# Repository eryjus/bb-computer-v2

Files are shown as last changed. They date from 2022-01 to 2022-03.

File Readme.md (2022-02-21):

# Breadboard Computer v2

This project is related to building hardware more than a software project.  There will be some code added to this project later on for programming the firmware and downloading a program, but that will be in the final stages.

This project is inspired by [Ben Eater's Breadboard Computer](https://eater.net/8bit).  Currently as this get started, I have his computer nearly complete and I am working on the final connections and debugging before I get into the control logic.

## Why?

I have always liked playing with hardware but never had any place to learn about it.  I stumbled on Ben Eater's 8-bit breadboard computer and it really sparked my interest.

OK, so why not build that one and call it a day?  Well, I did.  Or more the the point, I am.  However, there are some things I think need to be improved on.  Many of these come from my software developer (dare I call myself a software engineer?  I probably shouldn't) experience.

While I am completing the original computer and debugging it, it really all came to a head when all the control lines started to get in the way.

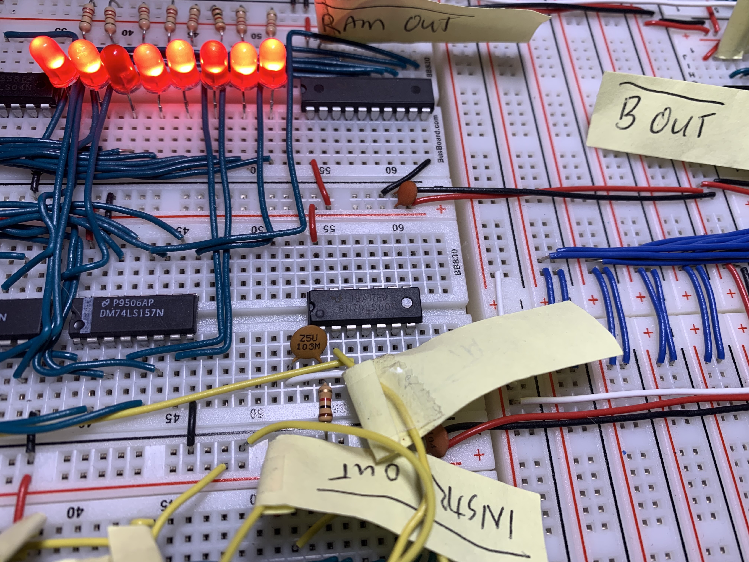
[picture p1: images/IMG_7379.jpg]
Control Lines


Not only are they all crushed down to the board to get them out of the way, but several leads were breaking from being worked so hard.

And then, there is the whole "active low" vs. "active high" issue.  There are a number of control lines which are active low meaning as long as you are asserting a "true" or 1 on the line it means, "Do not load any value from the bus."  This inversion in an interface point flicks my OCD buttons!  Big time!

## Videos

Hey, I tried it.  I made a few videos.  I did not like them.  I do not have the polish that Ben Eater does; I do not have the tools Ben Eater does.  Let's face it: he set a high standard and I cannot compete.

That said, I am also quite good at documenting my progress in projects.  I typically spend just as much time documenting as I do actually working on the project.  It helps me think things through (and believe it or not saves me time overall).

So, my goal is not to write a teaching video as Ben Eater did.  My goal is to document my progress as I go for others to review and enjoy -- and maybe get some ideas.  If you learn something from my mistakes, that's fantastic, too!

## Formal Experience?

Am I an electrical engineer?  No.

Do I have an extensive background in electronics?  No.

Am I learning as I go?  Yes.

Have I made mistakes?  Absolutely.

In fact: my first attempt at Ben Eater's Clock Module actually cooked one of the 555 Timer ICs.  I had to go find and order a replacement.  While I was at it I orders several other things I figured I would "break" along the way.  Now I have quite the collection going -- enough to prototype somethings on separate boards.

## Schematics

I was able to find KiCAD, an open source schematic drawing software.  It has natively all the elements that will be used to construct this computer.

I will be adding these files into the `kicad` folder in this project.

## Common Interface

I am going to be pulling the interface points to the edges of each board and making each row consistent for several interface points.  Additionally, all interface points will be converted to be active high.  As a result I will need to add an inverter to nearly all modules to properly handle that signal on-module.  But the point is to keep that kind of messiness away from the other modules.  Also, there are several modules which will have an inverter already on the module with unused gates.

Here is a picture of the updated Clock Module with the *clock* (white) and *output to bus* (yellow) interface rows tied together on the right side of the board.

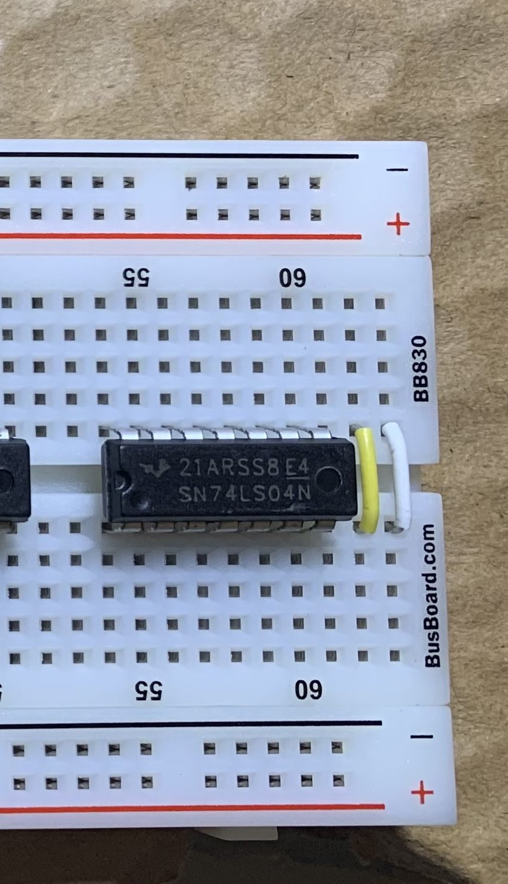
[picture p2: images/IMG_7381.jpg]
Interface Points


## Test Board

One of my goals is to be able to simplify testing of each module.  This is one of the driving reasons I am migrating to a common interface configuration.

To assist in this, I have created a test breadboard.  This board is intended to have all the inputs necessary to test the control lines and the outputs required to view the bus contents.  Here is a picture of this board:

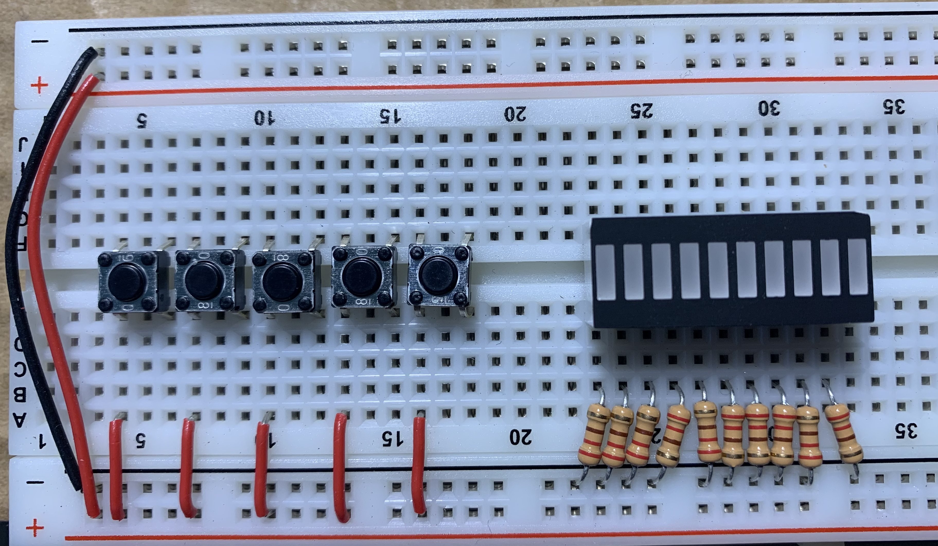
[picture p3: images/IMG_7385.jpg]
Test Board


The goal here is to quickly hook up wires and to be able to test the module functions more thoroughly before adding it into the final computer -- something I struggled to do with the original computer.

You have a high likelihood of finding my test rig in many of my pictures.

## 10-Segment LED Graph

I will replace the individual LEDs with a 10-segment LED graph for most modules (the most notable exception being the Clock Module).  These LED graphs have 8 green LED which will be used to represent data bits.  They also have an orange LED and a red LED which will be used to indicate reading data from the bus and writing data to the bus respectively.

With this change, the boards are able to get a higher density of LEDs and therefore a little more room on each board.  The drawback is that it will saturate the power rails for a section of the board and I may have to get creative when pulling power and ground to something else.

## Wire Colors

There are several color wires I plan to use -- a few more than Ben Eater used with the original computer.  These are:

| Color | Used for |
|:-----:|:---|
| Red | +5V or tied high |
| Black | Ground or tied low |
| White | Clock signal (regular or inverted) |
| Yellow | Control Lines |
| Blue | Data bus lines |
| Purple | Address lines |
| Green | Connections on-module |
| Brown | Manually input data and/or Arduino interface |
| Grey | Data Output (such as LED) and other connections not listed above |

## Overall Layout

| Left Column | Center Column | Right Column |
|:---:|:---:|:---:|
| (10) Clock Module | (20) Upper Program Counter | (30) Upper Temp 1 Register |
| (11) Upper MAR | (21) Lower Program Counter | (31) Lower Temp 1 Register |
| (12) Lower MAR | (22) Upper Flags | (32) Upper ALU |
| (13) Upper RAM | (23) Center Flags | (33) Lower ALU |
| (14) Lower RAM | (24) Lower Flags | (34) Upper Temp 2 Register |
| (15) Basic ROM | (25) Upper Stack | (35) Lower Temp 2 Register |
| (16) Upper A Register| (26) Lower Stack | (36) ALU Control 1 |
| (17) Lower A Register | (27) Bus Bridge | (37) ALU Control 2 |
| (18) Upper B Register | (28) Bus Contents | (38) ALU Control 3 |
| (19) Lower B Register | (29) CPU Constants | (39) Control Logic 1|
| (1A) Upper X Register | (2A) Upper Output | (3A) Control Logic 2|
| (1B) Lower X Register | (2B) Center Output | (3B) Control Logic 3|
| (1C) Reset Logic | (2C) Lower Output | (3C) Control Logic 4 |

## Modules

### Clock Module

The Clock Module is slightly modified version of [Ben Eater's Clock Module](https://eater.net/8bit/clock).  The schematic of his module is referenced below.

Ben Eater's Clock Module Schematic

The changes I am making to this module are:
1. Place yellow LED indicators on the astable and monostable timer circuits for visibility.
1. Place a green LED indicator on the switched circuit to show when the clock is in run mode (vs. single-step mode).
1. Add a red LED to indicate when the clock is halted by the control lines (the `HLT` signal).
1. Remove the inverted `CLK'` signal, which will be relocated to the Control Module where it is consumed.
1. Remove the OR gate and replace it with inverters and an AND gate (`A | B == (A' & B')'`).  See [2022-Jan-22 in the Journal](journals/Journal-01-Clock.md#2022-Jan-22) for a discussion and proof.
1. I am adding current-limiting resistors to every LED.  To be fair, Ben Eater's kits and instructions say that this is optional even though he does not use them in the videos.

### Program Counter Module

The Program Counter is nearly the same as [Ben Eater's version](https://eater.net/8bit/pc).  The original Program Counter is referenced below:

Ben Eater's Program Counter

Simply put, the changes the improved Program Counter are:
1. Make it a full 16-bits wide.
1. Since this is an 8-bit bus, make an upper and lower register, tied together.
1. There are 4 74LS161 counters tied together.
1. The original Program Counter had a bad habit of counting when it wasn't supposed to (on my boards anyway).  The improved Program Counter has a 100Ω pull-down resistor across Pin 2 of the lowest nibble 74LS161.
1. I use a 10-bar LED graph to indicate the data and control logic.  There are 8 green data LEDs, 1 yellow LED to indicate input from the bus, and 1 red LED to indicate output to the bus.  There is 1 graph for the upper Program Counter and another for the Lower Program Counter.
1. A 74LS04 Inverter was added to that the Control signals are inverted "locally" when required.  4 of the 6 inverters are utilized.

### Power-Up Reset / Zero Register Module

Ben Eater did not have this feature in the original computer.  The original computer had a reset button to clear everything on after manually programming.  I also plan to have a reset button, but I do not want to have to manually "reset" the computer on power up.

The reset button is tied into the power-up logic, not the Control Logic in the original computer.  The original computer's reset button can be seen [here](https://eater.net/schematics/control.png) in the bottom left corner of this schematic.

I also had problems getting the pull-down resistors to work properly on the bus.  Instead of pulling the bus values to 0, it left them floating.  I was not smart enough to figure out what the problem was, much less how to fix it (using the pull-down resistors anyway).  From the videos, I was not able to determine how this was tested.

Instead I made sure that every line was output to the bus even when there were only 4 bits to output (I tied the unassigned 4 bits low).  This cleaned up my problems.

In the improved version, I am going to add a Zero Register.  This register will output a 16-bit zero value on the bus and will be the default output register to the bus when nothing else is being output.

The Zero-Register is not really a register (more like a hard-coded zero value) and as such cannot be updated.

Since I have plenty of room on the Power-Up Module and the Zero Register will be placed on this board as well.  I am going to have plenty of boards.

### Arithmetic Logic Unit

The Arithmetic Logic Unit (ALU) is used to perform a number of operations between the values in 0, 1, or 2 registers.  In this implementation, the ALU and the Temporary Registers take several boards to complete.

The ALU also has a control module to handle a number of special cases with the Carry Flag and other flags.

The ALU supports 16 operations:

| ## | Operation | T1 | T2 |
|:--:|:---|:--:|:--:|
|  0 | NOT | Y  | |
|  1 | AND | Y  | Y  |
|  2 | NAND | Y  | Y  |
|  3 | OR | Y  | Y  |
|  4 | NOR | Y  | Y  |
|  5 | XOR | Y  | Y  |
|  6 | XNOR | Y  | Y  |
|  7 | FALSE | | |
|  8 | TRUE | | |
|  9 | ADD | Y  | Y  |
| 10 | SUB | Y  | Y  |
| 11 | SHL | Y  | |
| 12 | INC | Y  | |
| 13 | DEC | Y  | |
| 14 | ADC | Y  | Y  |
| 15 | SBB | Y  | Y  |

### General Registers

There are 8 basic registers that are included in this updated computer, not counting the Program Counter.  These are:
* A Register (Software accessible)
* B Register (Software accessible)
* X Register (Software accessible)
* Stack Register (Software accessible)
* Output Register (Write only; Software accessible)
* Memory Address Register (MAR)
* Temporary Register 1 (TR1)
* Temporary Register 2 (TR2)

## Control Signals

It occurs to me early on that I need to keep track of the control signals I am requiring, and what module they are associated with.

| ## | Module | Control Signal |
|:--:|:---:|:---:|
| 1  | Clock | Halt |
| 2  | Program Counter | Clear |
| 3  | Program Counter | Enable |
| 4  | Program Counter | Upper Byte In (JMP) |
| 5  | Program Counter | Upper Byte Out |
| 6  | Program Counter | Lower Byte In (JMP) |
| 7  | Program Counter | Lower Byte Out |
| 8  | Power-Up Reset  | Zero Register Out |
| 9  | Temp Register 1 | Clear |
| 10 | Temp Register 1 | Upper Byte In |
| 11 | Temp Register 1 | Upper Byte Out |
| 12 | Temp Register 1 | Lower Byte In |
| 13 | Temp Register 1 | Lower Byte Out |
| 14 | Temp Register 2 | Clear |
| 15 | Temp Register 2 | Upper Byte In |
| 16 | Temp Register 2 | Upper Byte Out |
| 17 | Temp Register 2 | Lower Byte In |
| 18 | Temp Register 2 | Lower Byte Out |
| 19 | ALU | Upper Byte Out |
| 20 | ALU | Lower Byte Out |
| 21 | ALU | Function Select 0 |
| 22 | ALU | Function Select 1 |
| 23 | ALU | Function Select 2 |
| 24 | ALU | Function Select 3 |

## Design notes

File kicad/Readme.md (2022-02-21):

# Kicad Drawings and Computer Organization

Before you get into the Kicad schematics, I want to touch on the computer layout a bit.  Overall, the computer is laid out in 3 columns with a bus between each column.

There are several breadboards in each column, with columns 1 & 3 having 13 breadboard and the middle column (2) having 12.  The extra space is taken up with a "bus bridge" to link the 2 buses together.

This is important for these drawings since the naming convention will indicate the breadboard location for any given schematic.  However, the computer is also organized into modules and some components may exist on a separate breadboard.

As an example, each 16-bit register has a 74LS04 Quad-AND Gate and a 74LS08 Hex-Inverter.  Each register is built on 2 breadboards.  One will have the 74LS04 and the other will have the 74LS08.  However, all the logic symbols will be located on a single schematic.  These facts need to be taken into account if you want to duplicate the boards.

So, that said, each schematic drawing will have a 2-character location specification where:
* the first character indicates its column (1, 2, 3)
* the second character indicates which row (hex from 0 to C)

See the [computer layout](../Readme.md#overall-layout) for more information.

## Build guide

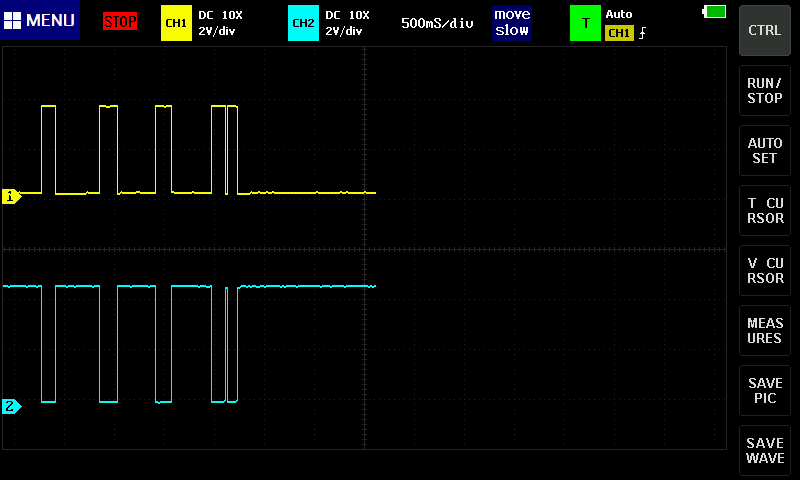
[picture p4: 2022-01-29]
images/manual bounce.bmp

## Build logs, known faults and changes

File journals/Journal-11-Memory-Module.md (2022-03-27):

# Breadboard Computer v2

This project is related to building hardware more than a software project.  There will be some code added to this project later on for programming the firmware and downloading a program, but that will be in the final stages.

This project is inspired by [Ben Eater's Breadboard Computer](https://eater.net/8bit).  Currently as this get started, I have his computer nearly complete and I am working on the final connections and debugging before I get into the control logic.

As usual with my personal projects, I am compelled to keep a journal of this progress.  As usual with my journals, I will not go back and edit anything historical as these are my continuing thoughts rather than documentation of the final product.

## Memory Address Module

This module is actually 2 registers and an adder:
* Memory Address Register (MAR) -- this will be an internal register which will be used to set a base memory address, typically from the Stack Pointer or Program Counter
* Memory Index Register (MIR) -- this will be an offset (forward or backward) from the Memory Address Register; every access to memory will use this Register and as such may be 0 much of the time
* Memory Address Adder (MAA) -- this will add the MAR and MIR together and the result of this operation will be used for every Memory access
* Memory Address Proper (MAP) -- this will be the actual address which will be used for every memory access

Each of these will only load values from the bus (none will output values to the bus).  Contrast that with the need to output the *contents* of the memory at the Memory Address Proper to the bus, which is a future module.

That said, this module will take a bit to build.  Each of the 4 sections above will be included in this module and Journal file.

---

## Memory Address Register (MAR) Sub-Module

---

### 2022-Feb-01

I'm not going to lie: for a little while I thought I could lay out the MAR on one board.  Actually, I can.  I thought I could keep the upper address byte on the top of the board and the lower on the bottom.  I can.  I was hopeful I could save a board.  I could.

*Except....*

The 8 lined that need to be brought down to the adder had absolutely no room on the breadboard and would need to be routed off-module or looped over the ICs.

I decided to keep the MAR separated to 2 breadboards.  This is consistent with the initial expected layout.  The dry layout (before wires) is very sparse:

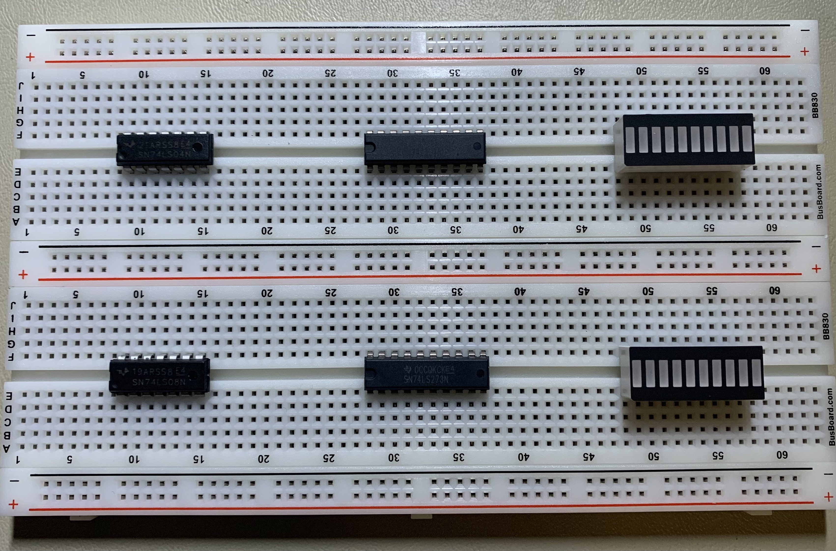
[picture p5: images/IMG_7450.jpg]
Memory Address Register Dry Layout


Notice that there is no 74LS245 IC -- since there is no need to output to the bus, there is no need for a tri-state buffer.  This saves me an IC on each breadboard.

Also (though it is not evident in the picture), the LED is facing the opposite direction so the cathodes are on top rather than on the bottom as with all the other modules built so far.  This will mean I do not want to attach this module to the Clock timer *after* it is built.  I will be assembling this attached to the Clock Module; please understand this fact when it makes an inevitable appearance in the pictures.

---

Now, I probably should consider how I am going to program the memory remotely.  I do plan on using an Arduino Nano to accomplish this.  For this to happen, I am going to need to set the MAR, MIR (to 0), and then populate the data on the bus and trigger a write from the bus to memory.

For this to work, I need to be able to load the MAR from 2 sources:
* From the bus when in run mode
* From the Arduino registers when in program mode

I will probably need to add a 74LS157 (2-to-1 decoder) to pull the address from the proper source.  Since the 74LS157 is a 4-bit decoder, I will need 4 of them.  Alternatively, I can program the upper and then lower MAR bytes separately and use twice the clock cycles to accomplish the programming cycle.

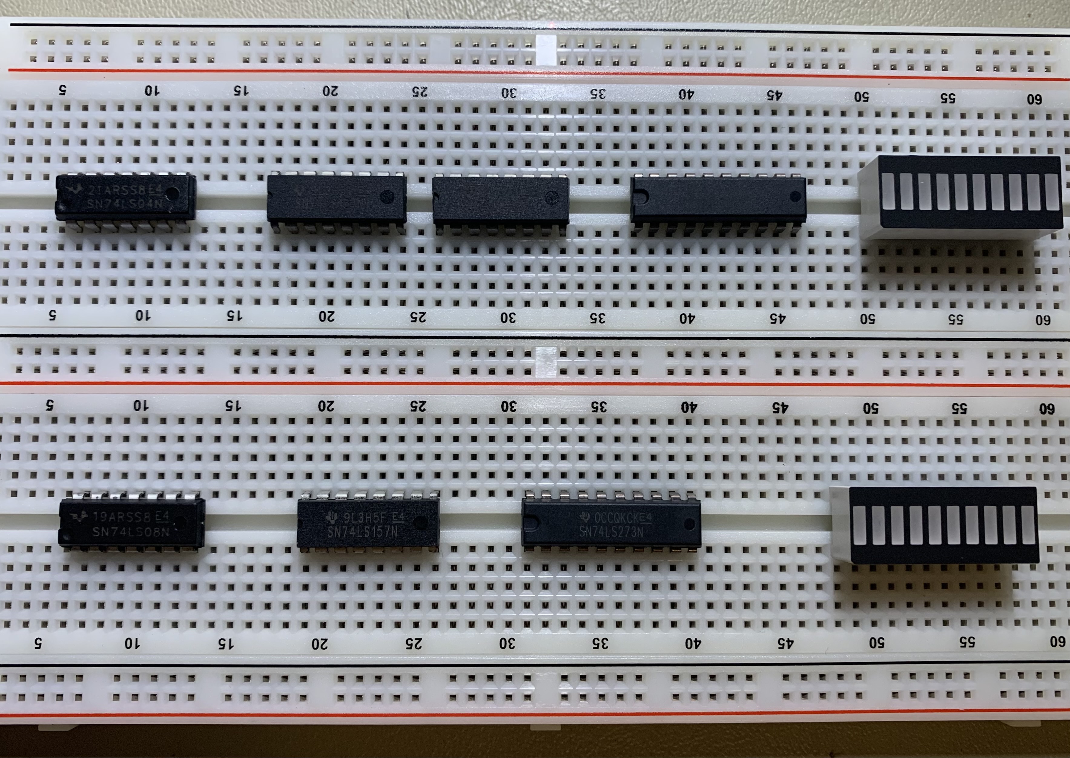
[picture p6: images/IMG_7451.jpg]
Sample Layout


The upper board would be if I was able to set all 16-bits of the address at the same time.  This would add ICs and reduce programming time.  I am concerned about power already.

The lower board would be if I was to set the upper and lower bytes separately.  This would effectively double the time it took to program the RAM.

A third alternative is to integrate directly into the bus and control logic so that there was effectively 2 sets of control logic.  I actually like the elegance of this design -- to take over the computer to program the RAM.  And this means I do not have to do anything special for the MAR.  But I may have to change the Clock Module to accommodate the separate clock source.

Hmmm.... I wonder if I could use a diode to keep the clock signal from back-bleeding into the clock and vice-versa from the Arduino....  I am going to order some and play with them on a board and oscilloscope.  In the meantime, I will do the foundational wire-up.

---

### 2022-Feb-02

I have the MAR completed.  It really was a simple wire-up.

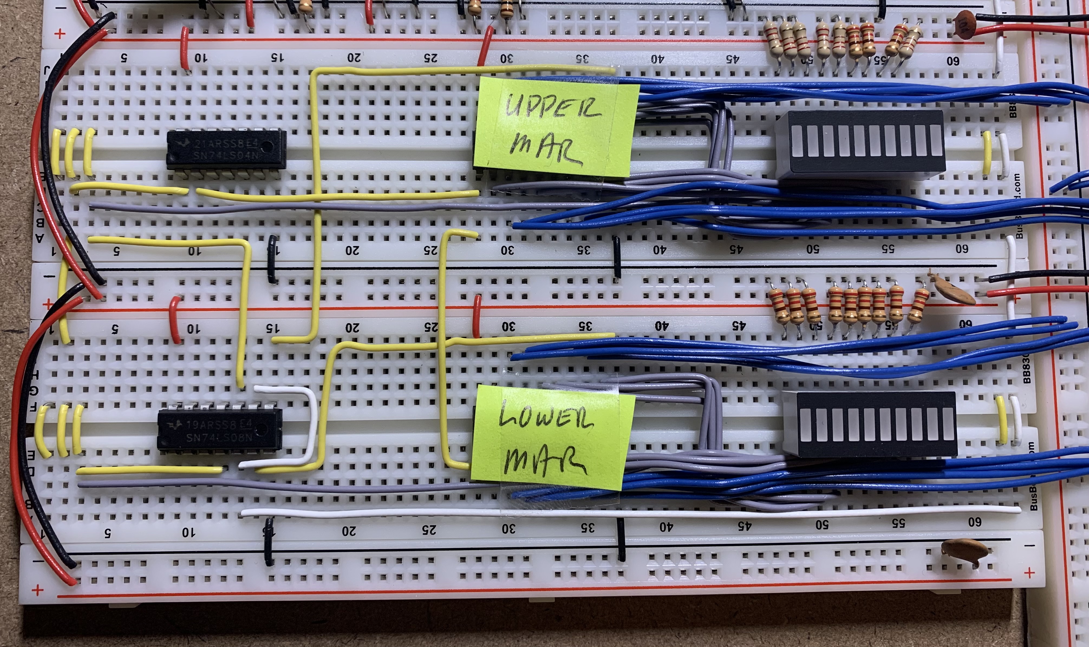
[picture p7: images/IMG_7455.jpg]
Completed MAR


It is also hooked up to the bus, along with all the other completed modules.

So, with this, I move on to the Memory Index Register (MIR).  It happens to be a complete duplicate of the MAR.  So...., second verse; same as the first!

---

## Memory Index Register (MIR) Sub-Module

This sub-module will be located immediately below the MAR.

---

### 2022-Feb-02 (continued)

The question is whether I leverage the MAR's existing 74LS04 and 74LS08 chips, which have enough capacity to host the MIR requirements.

The Inverter is only using 1 of 6 gates.  This is very wasteful.  The AND gate is 50% populated.  Again this is wasteful.  Especially since I am concerned about power.

The layout is still tight, but this is far more doable by splitting the 74LS04 & 74LS08 over 2 boards.

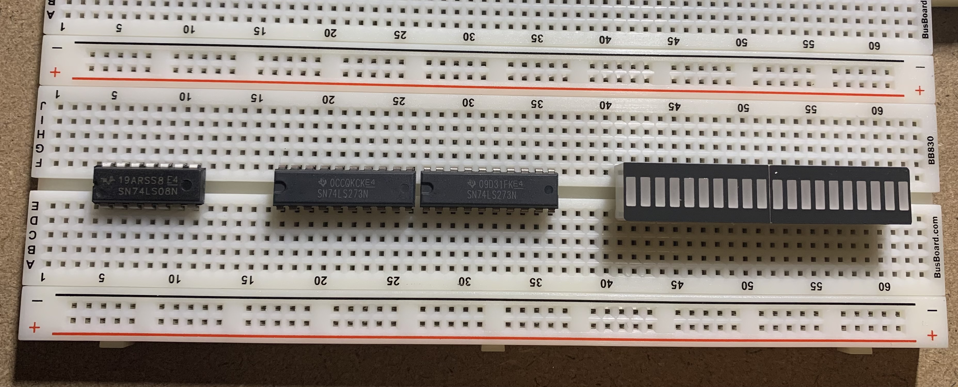
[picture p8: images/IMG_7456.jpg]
Layout for MAR & MIR on 2 boards revisited


I think the key to making this work is that the 74LS08 (AND gates) will be fully populated and if I need another AND gate, it will be in the adder or in the Memory Address Proper (MAP); however, the 74LS04 (Inverter) still has capacity and can be leveraged for the adder or the MAP.  So, the 74LS08 needs to be placed with the MAR whereas the 74LS04 can be placed with the MIR.

Of course, this means I need to tear up the MAR and redo it.

---

I knew things would get tight with the LED graphs..., and they did!

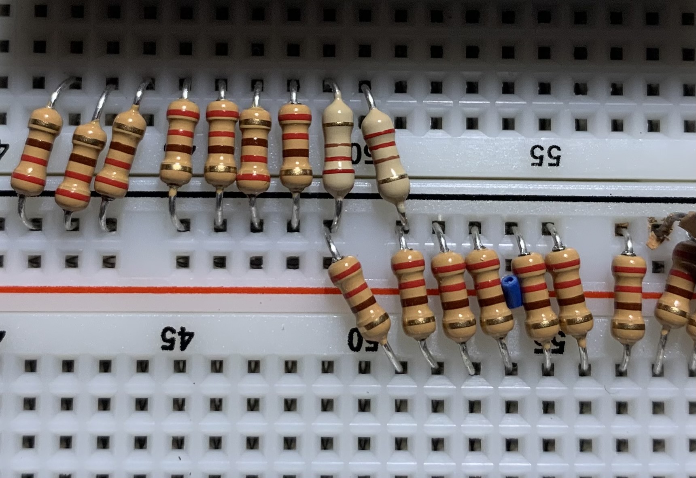
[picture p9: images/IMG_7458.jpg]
Tight Connections


Yes, there are 2 resistors doubled up in the ground connection.  I'm going to live with it for now.

I still have foundational connections to complete (again), but I am not up for all that (again) tonight.

---

### 2022-Feb-03

Today I completed the control lines.

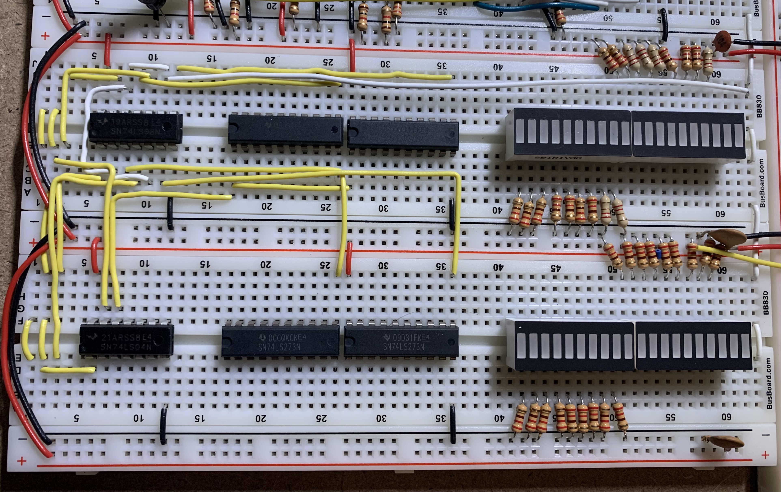
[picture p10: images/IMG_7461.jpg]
Control Lines Wired


---

Also, as a side note, I started working on a bench-top power supply from an old retired ATX power supply.  This old power supply is a 750W monster and will provide plenty of DC power for nearly all my needs.

I am not going to document this project, as there are plenty of videos and the like on how to do this.  I will post a picture of the results in a future journal.

---

### 2022-Feb-04

Well, last night I was able to get the MAR re-wired.  In the end it looked like this:

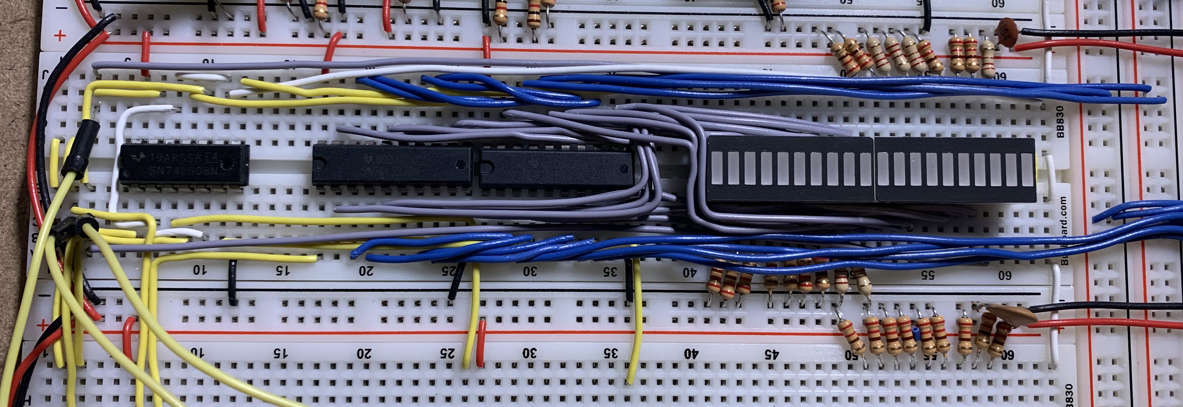
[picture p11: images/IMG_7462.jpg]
MAR Wired-Up Again


Today, I tackled the MIR and got that wired up as well.

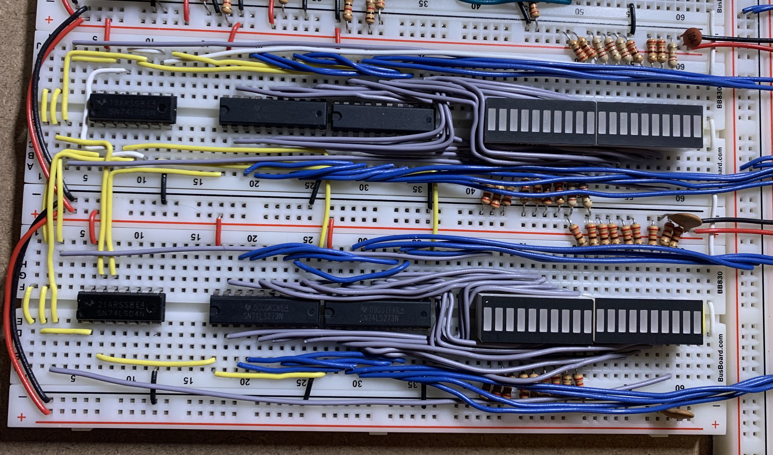
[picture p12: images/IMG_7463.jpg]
MIR Wired-Up


Both registers are properly tested (and in fact I had to wire the output of the MIR twice).

The next step is to bring the 2 register values down to a 16-bit adder.  The adder is responsible for summing the MAR and the MIR to get a aggregated address from which the memory will be read.

The MAA and the MAP will probably need to be built at the same time so that the proper contents can be evaluated.

Well, I just realized my last order was mis-picked.  This means I am unable to complete the MAA, which means I cannot complete the MAP.  Damn!

---

### 2022-Feb-05

I am approaching the point in which I need to also place the RAM onto the system.  I will also need to place that in the order to replace the adder chips.

---

### 2022-Feb-06

While I am waiting for the replacements, I have a couple of options.
1. I can wire up the A Register (which is a duplicate of the Temporary Register which has already been completed).
1. I can work on documenting the MAR and MIR schematics.
1. I can work on how I am going to handle the flags register.

I think I will work on the MAR/MIR schematics.

Actually, since the connections are off-sub-module, I may have a tough time combining them into a single schematic.

---

OK, here is the MAR schematic:

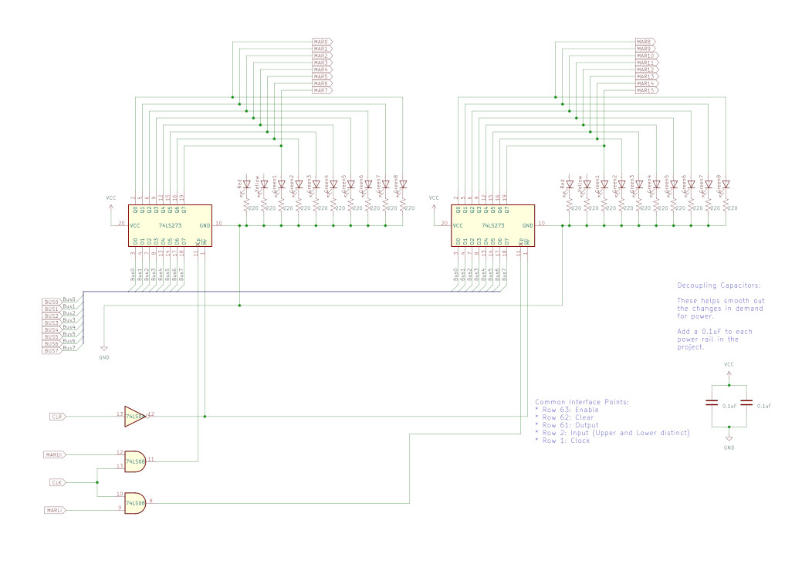
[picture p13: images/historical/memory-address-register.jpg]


The MIR will end up being a copy of this, with some minor changes.

Copy-and-paste is a wonderful thing:

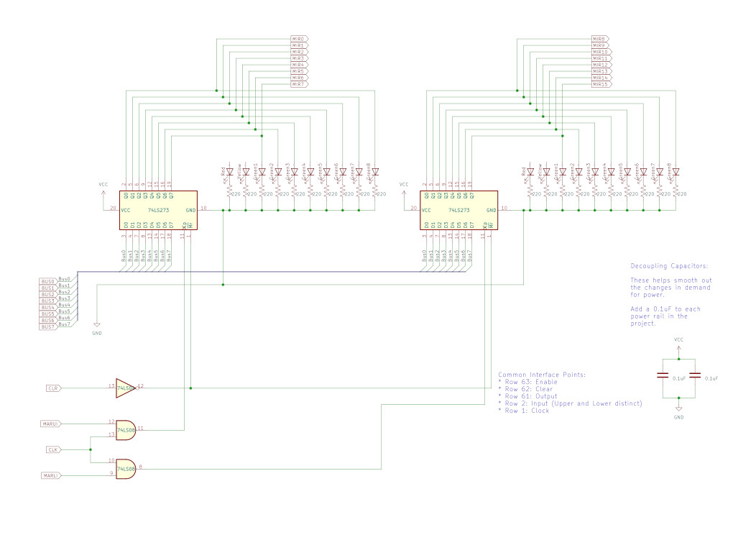
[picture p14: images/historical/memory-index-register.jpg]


The look the same, but the off-schematic connectors are named different.  Take a close look.

---

Now, in the meantime, I will work on the A Register.

---

### 2022-Feb-11

Well, I had a but of an epiphany yesterday while I am out and about: Why am I worried about stupid optimizations when I need to be worried about getting this iteration completed.  As such, why do I need a MAR, MIR, MAA, and MAP when all I really need is a MAR and an ALU.  The same question goes for the stack: why do I need it when I can use the ALU?  Yeah, it may take an extra clock cycle or two, but I am going for the blinking lights more than I am going for speed.  If I want speed, I will buy another laptop.

So, I need to go back and revisit my work on the Memory Address Module (which will be torn down and redone), and the A and Temporary Registers (as they may be relocated and need to be flipped.

With that said, I am going paste this same update into all 3 Journals since they will all need to be revisited.

---

### 2022-Feb-25

OK, my direction here has changed (see the last update above).  As such, the current Memory Address Register needs a complete gut and redo (or maybe just some selective surgery if I can).

At the same time, this file will be renamed to align with the new naming standards and the schematics will be updated as well.  I have a MIR schematic which will need to be deprecated, but I'm sure I have some images herein to relocate for posterity.

Here is my starting point today (separated from the rest of the computer):

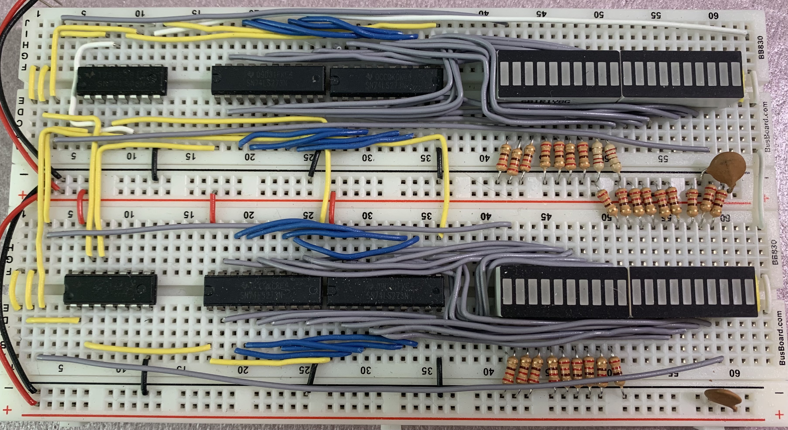
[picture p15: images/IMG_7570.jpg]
MAR Before Redo


If feels like kindergarten craft hour!

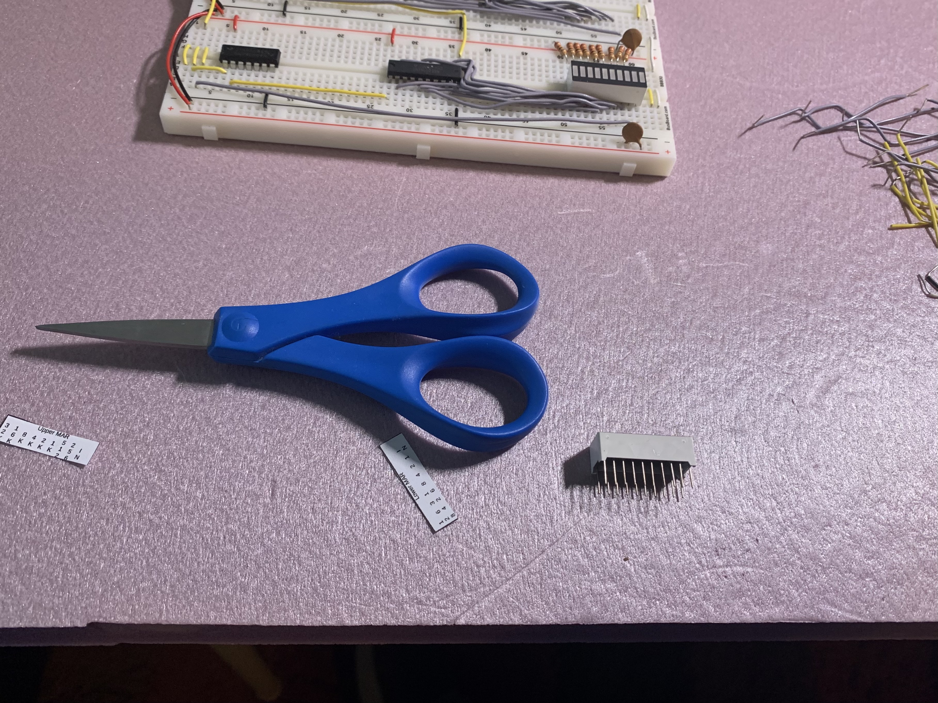
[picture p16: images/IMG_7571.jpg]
Craft Hour


And, I think I have the MAR all cleaned up:

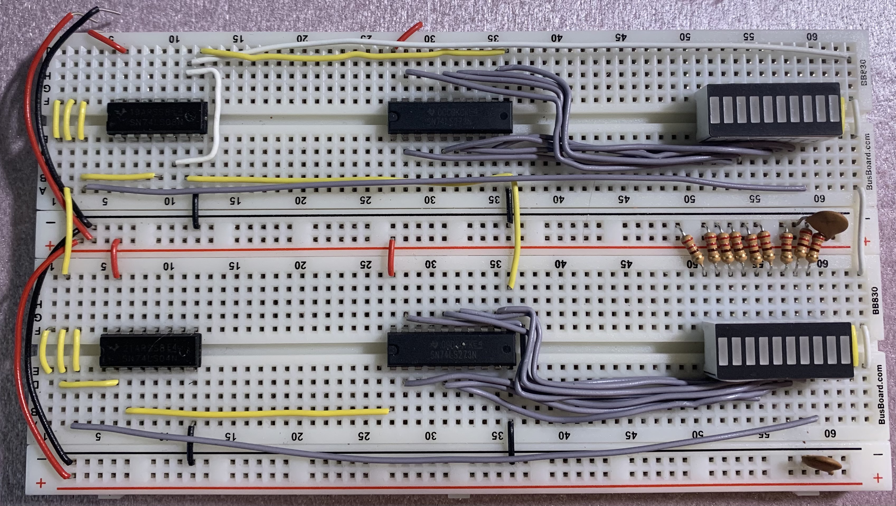
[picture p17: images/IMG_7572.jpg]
New MAR


It is, of course, untested as of yet.  Next step will be to hook this back up to the whole computer and perform some testing.

Well, the Upper MAR is wired backwards.  Just like the Temporary Registers were.

---

OK, after a small break, I was able to get that rewired properly.  It also tested out properly.

---

### 2022-Feb-27

The task today is to get the schematics updated.

Done:

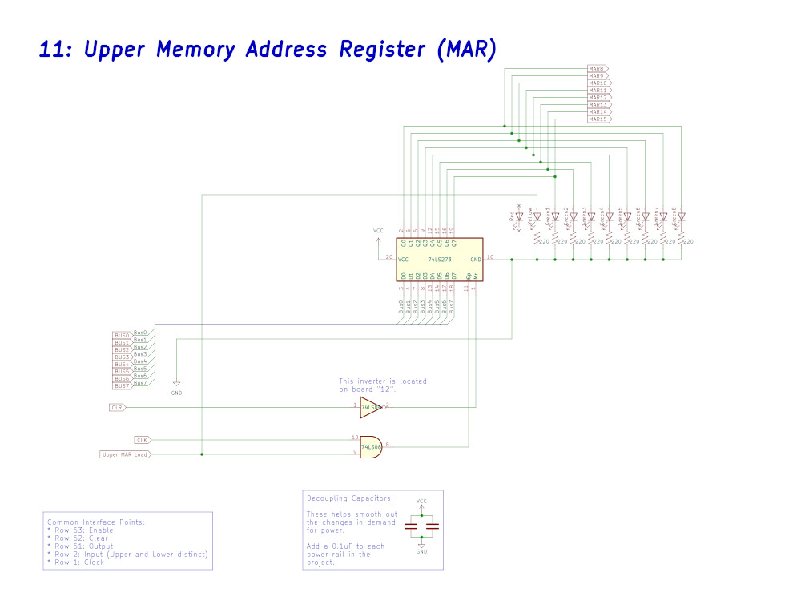
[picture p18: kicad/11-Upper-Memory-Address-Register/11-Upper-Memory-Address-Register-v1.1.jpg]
Upper MAR


... and the lower:

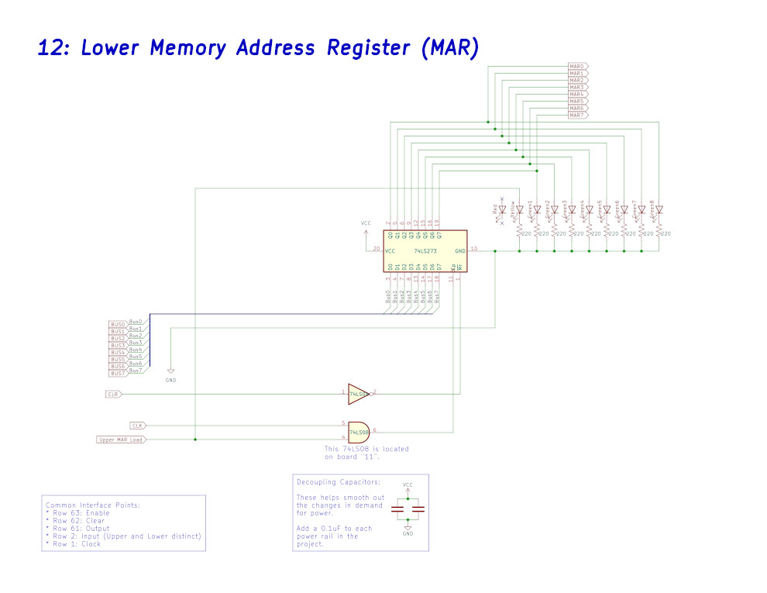
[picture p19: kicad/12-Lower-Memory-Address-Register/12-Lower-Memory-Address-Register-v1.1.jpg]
Lower MAR


---

Now, there is going to be a RAM and a ROM component to the memory.  ROM will be located from `0xd000` (or maybe even `0xc000`) to `0xffff` (12K - 16K total ROM memory).  So, this means that addresses from `0x8000` to `0xcfff` all need to be handled by RAM.

So, I can discern which to handle based on the most significant 4 bits, in the following manner:

| Bit 15 | Bit 14 | Bit 13 | Bit 12 | Address | Memory |
|:---:|:---:|:---:|:---:|:---:|:---:|
| 1 | 0 | 0 | 0 | 0x8000  | RAM |
| 1 | 0 | 0 | 1 | 0x9000  | RAM |
| 1 | 0 | 1 | 0 | 0xa000  | RAM |
| 1 | 0 | 1 | 1 | 0xb000  | RAM |
| 1 | 1 | 0 | 0 | 0xc000  | ROM |
| 1 | 1 | 0 | 1 | 0xd000  | ROM |
| 1 | 1 | 0 | 1 | 0xe000  | ROM |
| 1 | 1 | 1 | 1 | 0xf000  | ROM |

Actually, Bit 15 is always set.  So it should be trivial to determine if I am working with the Upper RAM/ROM or the Lower RAM.  So, assuming that we are halved to the upper RAM/ROM, the next 3 bits will determine RAM vs. ROM.  And looking at it, I am going to go ahead and make the call that the ROM will be from `0xc000` and above.  This makes the determination only 1 bit from the Upper RAM/ROM module.  However, this decision means I can work mostly from the top 2 bits and inverters (with a small handful of AND gates).

For the inverters, I need:
* Upper In
* Upper Out
* Lower In
* Lower Out
* (Pin 15 & 14) selection

For the AND Gates, I need:
* CLK & Upper In
* CLK & Lower In
* Pin 15 & Pin 14

Hmmm....  This is not right.  I am forgetting that the whole point of this is to present a single byte to the bus.  I may need some more logic gates to make that work.

So, the following table will be used to determine which chip is enabled:

| Bit 15 | Bit 14 | Address Range | Memory |
|:---:|:---:|:---:|:---:|
| 0 | 0 | 0x0000-0x3fff | Lower RAM |
| 0 | 1 | 0x4000-0x7fff | Lower RAM |
| 1 | 0 | 0x8000-0xbfff | Upper RAM |
| 1 | 1 | 0xc000-0xffff | ROM |

So, the truth table for Lower RAM should be simple (`CE` set low):

| b15 | \CE |
|:---:|:---:|
|  0  | 0 (Enabled)  |
|  1  | 1 (Disabled) |

The truth table for Upper RAM is:

| b15 | b14 | \CE |
|:---:|:---:|:---:|
|  0  |  0  | 1 (Disabled) |
|  0  |  1  | 1 (Disabled) |
|  1  |  0  | 0 (Enabled)  |
|  1  |  1  | 1 (Disabled) |

So `NOT (b15 AND (NOT b14))`.  I think this can be reduced to `b15 NAND (NOT b14)`.  Let's see:

| b15 | b14 | \b14 | Res |
|:---:|:---:|:----:|:---:|
|  0  |  0  | 1  |  1  |
|  0  |  1  | 0  |  1  |
|  1  |  0  | 1  |  0  |
|  1  |  1  | 0  |  1  |

This gives the result I am looking for.

The truth table for ROM is:

| b15 | b14 | \CE |
|:---:|:---:|:---:|
|  0  |  0  | 1 (Disabled) |
|  0  |  1  | 1 (Disabled) |
|  1  |  0  | 1 (Disabled) |
|  1  |  1  | 0 (Enabled)  |

So, `NOT (b15 AND b14)`.  This should also be able to be reduced to `b15 NAND b14`.  Let's see:

| b15 | b14 | Res |
|:---:|:---:|:---:|
|  0  |  0  |  1  |
|  0  |  1  |  1  |
|  1  |  0  |  1  |
|  1  |  1  |  0  |

So, I will need the following Logic Gates:
* 74LS04 -- RAM Out
* 74LS04 -- NOT b14
* 74LS08 -- CLK AND RAM In
* 74LS00 -- Upper RAM Chip Enable
* 74LS00 -- Upper ROM Chip Enable

---

### 2022-Mar-02

Well I got my supplies today, which includes the ROM memory.  I also have a new Arduino and a couple of shifters to handle programming the larger memory.

OK, thinking about this, I may have a problem here.  I have 4 places a byte can come from but I did not consider ORing the outputs together.  I really need to download and read the data sheets for the RAM and ROM to see if it really is a tri-state output before I wire it all together.  I actually have a bit of a headache tonight, so I am not going to do too much research today.  I am looking for some light-weight work to do.

---

### 2022-Mar-03

OK, data sheets....

The 28C16 reads a "High Z" output when Output is disabled, or when OE is high.  The CE (Chip Enable) also produces "High Z" when the pin is high.

On the other hand, the static RAM is "High Z" when the CS (Chip Select) is high.

So, as long as only 1 chip is active at any given point, I think I can wire all the I/O pins together.

I think the first thing I need to do is to get the different chips to be enabled at the correct points.

---

I have problems.  My truth tables are all messed up.  So, let's look at this again.

* 0x0000 to 0x7fff is the lower RAM chip
* 0x8000 to 0xbfff is the upper RAM chip
* 0xc000 to 0xdfff is the lower ROM chip
* 0xe000 to 0xffff is the upper ROM chip

Looking at the top 3 bits, I get the following:

| Bit15 | Bit14 | Bit13 | Chip |
|:-----:|:-----:|:-----:|:---:|
| 0 | 0 | 0 | Lower RAM |
| 0 | 0 | 1 | Lower RAM |
| 0 | 1 | 0 | Lower RAM |
| 0 | 1 | 1 | Lower RAM |
| 1 | 0 | 0 | Upper RAM |
| 1 | 0 | 1 | Upper RAM |
| 1 | 1 | 0 | Lower ROM |
| 1 | 1 | 1 | Upper ROM |

The key I forget was that I need to not only enable one chip but I need to disable everything else.  There is a 74LS138 which I can use to select the proper chip, and the outputs are inverted.  It also makes handling the Lower RAM address range difficult to manage.  There is also a 74LS139 which is a Dual 2-to-4 decoder.  Again the output is inverted.

But I honestly think I am over-thinking this.  Lower RAM can be selected when Bit15 is low.  Let me get thats working first.  This will mean that the Upper RAM chip is dark when the others are lit.

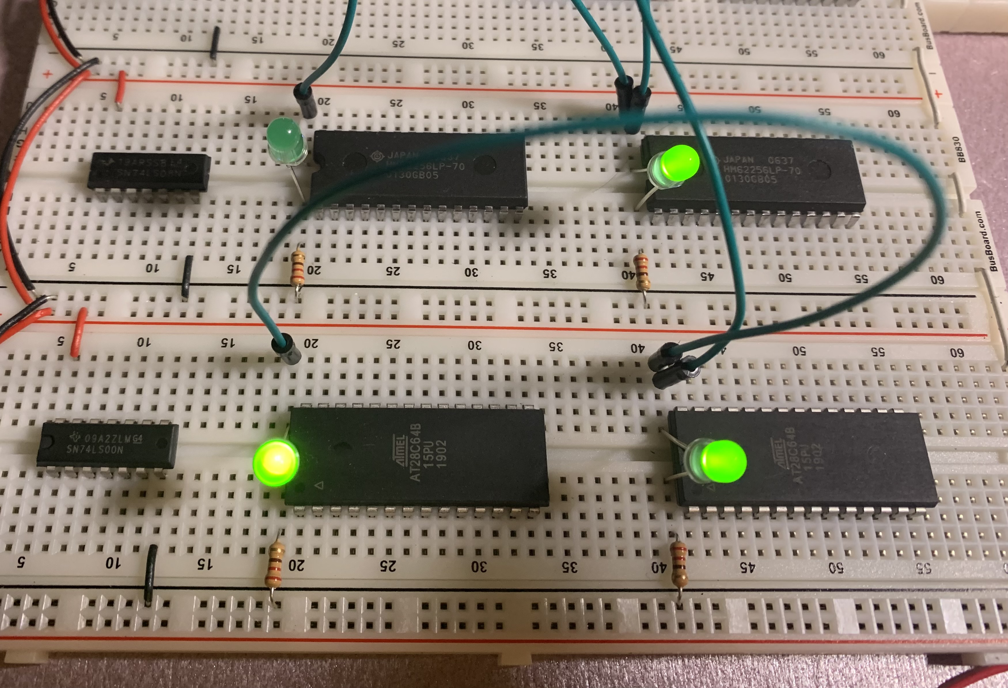
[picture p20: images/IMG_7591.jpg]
Upper RAM properly selected


Now, for the Lower RAM chip.  This is when Bit15 is high but Bit14 is low.

The original un-simplified logic was correct: `NOT (b15 AND (NOT b14))`

---

OK, I did finally get this wired up properly.  It was more of a brute force method, but it is working.  I could probably simplify it, but I'm not going to try.

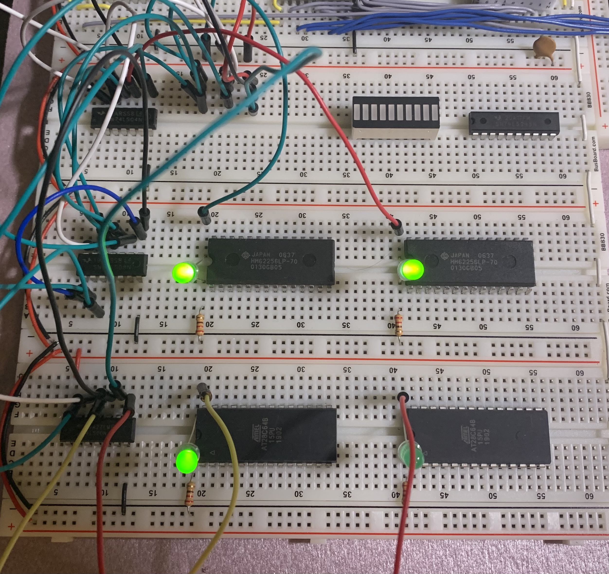
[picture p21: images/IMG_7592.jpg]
Test-Wired for Chip Selection


I will work on more permanent wiring tomorrow.

---

### 2022-Mar-04

I was able to get pin 15 wired up.  I also used another inverter to make the LED light up properly.

---

### 2022-Mar-05

Today I start with pin 14, which will be a little more complicated to wire up properly.

I was also able to get pin 13 wired up as well.  That should be all the complicated ones.  The problem is going to be to squeeze in all the "easy" ones.

---

### 2022-Mar-06

This morning I realized I had not completed the foundational wire-up for the RAM/ROM module.  That was fun to do with all the other wires already in place.  But, I did get it done.  I think all I have left for this module are:
* Tie /OE low for all chips
* Wire up all the address lines (0-11)
* Wire up all the outputs to the LED and 74LS245
* Connect the 74LS245 to the bus

---

### 2022-Mar-07

OK, this is starting to get under my skin!  Somehow the chip selection is no longer working like it was.  I am going to have to pull the hook-up wires just to try to debug.  I am bouncing around between too many things and I need to focus on 1 until I have it working properly.  I think I am going to take on this Memory Module and make it work.

I was able to get the control logic reset properly again.  Not sure what happened, but it did.

I also realized that I am going to need to wire up the 74LS245 as an actual transceiver, so pin 1 will control input and output direction.  Shit, no, that's not it.  Well, not all of it.

Pin 19 needs to be set when either in or out are set.  I need an OR gate for this.  Then pin 1 needs to be set when the output line is set, which is a trivial wire-up.  I actually have a 74LS32 with 1 bad OR gate, which I am going to leverage here.

OK, that is wired up properly.  So, now I have the following features with the memory:
* Only 1 memory chip is active at a time.
* All chips' outputs are wired together and to the transceiver and output LEDs, meaning I can always see what is in the contents of the memory indicated by the MAR.
* The transceiver isolates the memory unless we are inputting from or outputting to the bus.
* For RAM, when OE, CE, and WR are all tied low, the RAM writes to memory (correct).
* For the ROM, I will need to tie CE and OE together so that the chips are not outputting if an attempt is made to write to a ROM addresses.

So, this time I will be setting the control lines as yellow (not purple) and the LED indicator lines as grey (again) so I can better determine what is really going on.  The lines connecting the chips together will all be green.

---

OK, I have the Memory Module wired up to the point I thought I had gotten to last night.  That's 8 of 16 address lines wired up.  I have 8 more to do.  The good news is that these are all on the same side of the chips.  That said, stripping all those wires and bending them properly is hard on my fingers.  I am going to take a break on this tonight.

---

### 2022-Mar-10

I was able to get some additional address lines wired up today.  This is all very dense wiring so I am not having so much fun with this part.

---

### 2022-Mar-11

Here are the space constraints I am dealing with at this point:

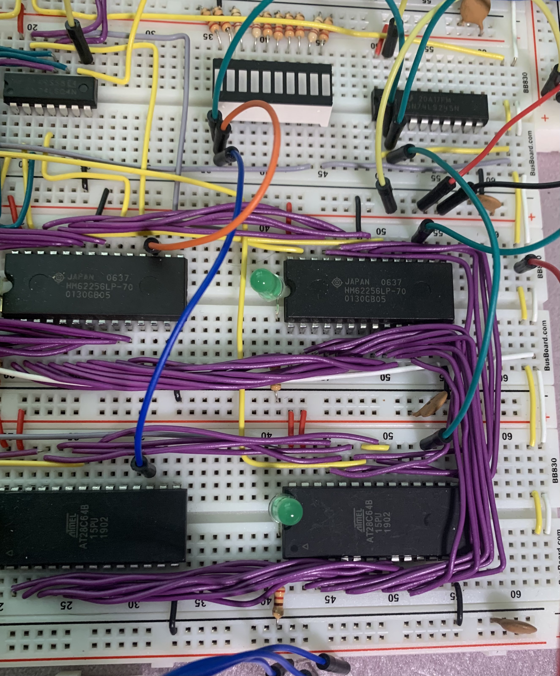
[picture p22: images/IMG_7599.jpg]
Tight Spaces


In the bottom-right and top-right corners of each chip, I need to be able to get the I/O lines routed.  There really is very little space for these lines and certainly not enough to double up anything like I did the address lines.

The fix for this problem is going to be to direct wire each chip to the output node (rather than by chaining them together).  The temporary lines show an example of this wiring.

I also discovered that I need to invert the enable line on the 74LS245 -- it was always-on the way I had it wired up.  That should be a relatively simple fix and I'm glad I caught that before I started all the I/O line wiring.

That fixed, I am going to tackle handling the LED-to-74LS245 jumpers.

---

OK, I was able to get the Memory Module wire-up completed.  Like the ALU, there is a dense amount of wiring.

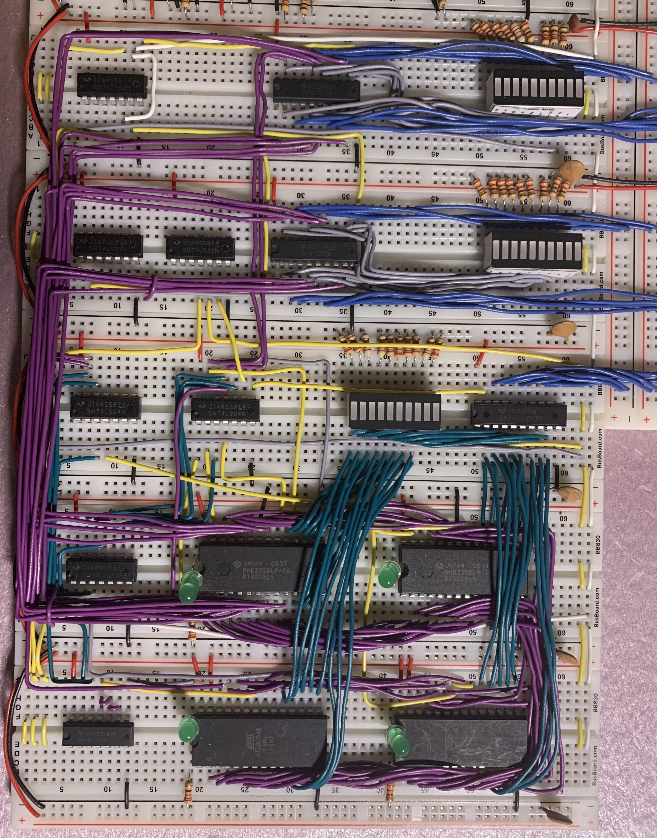
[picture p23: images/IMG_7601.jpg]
Completed Memory Module Wire-Up


It will be hard to get to the ROM EEPROMs to program them.  So, the emulator will need to be a feature of this build to try to work out as many bugs in the firmware as possible.

I do need to test.  And create schematics.

Tomorrow.

---

### 2022-Mar-12

OK, this is working.  Mostly.  Somewhat.  Kinda.

The problem is that I am not totally certain I can describe the problem.  There does appear to be some bleed-over between the different chips, such that when I try to output to the bus I see some additional LEDs come on.

And then the problem just went away.

Which means I still have *some* problem to solve.  But right now I cannot describe it.

I'm going to need to think on this a bit and figure out what to measure.

---

Had I been thinking about it, I would have put the memory contents at the bottom rather than between the MAR and the RAM/ROM modules.  Oh, well!  Too late now....

---

OK, I think I have board "13" ready.  Here is the schematic:

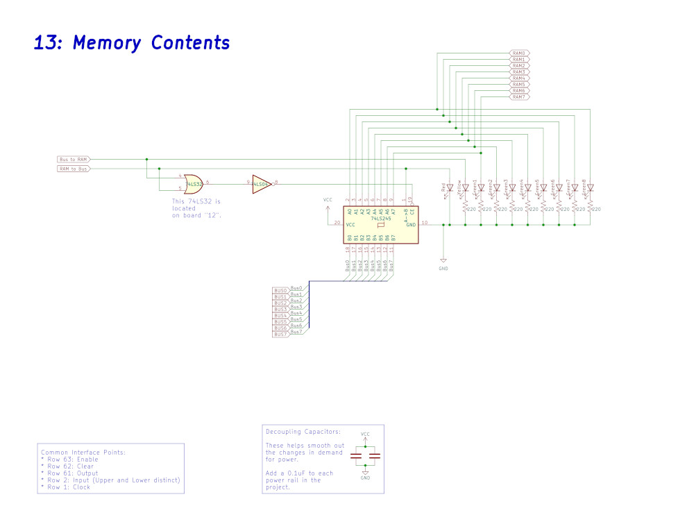
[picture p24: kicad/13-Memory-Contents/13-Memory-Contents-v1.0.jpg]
Board 13 -- Memory Contents


Next will be the RAM board, which has some more complicated logic for the pin selection.  But I have the fuck-its today and really don't want to do this busy work.  Maybe I can motivate myself -- or just suck it up and get it done.

---

### 2022-Mar-19

I am going to bypass the rest of the schematics until I am ready to order PCBs.  The reason is that the entire schematic will need to be redone if I go down that route.  And I do plan to go down that route.

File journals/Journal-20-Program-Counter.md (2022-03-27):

# Breadboard Computer v2

This project is related to building hardware more than a software project.  There will be some code added to this project later on for programming the firmware and downloading a program, but that will be in the final stages.

This project is inspired by [Ben Eater's Breadboard Computer](https://eater.net/8bit).  Currently as this get started, I have his computer nearly complete and I am working on the final connections and debugging before I get into the control logic.

As usual with my personal projects, I am compelled to keep a journal of this progress.  As usual with my journals, I will not go back and edit anything historical as these are my continuing thoughts rather than documentation of the final product.

## Program Counter Module

The next module to build will be the Program Counter Module.  This module will have a 16-bit counter (compared to the 4-bit counter in the original computer).

---

### 2022-Jan-23

Now is as good a time as any to get into a conversation about having 16-bit registers and an 8-bit bus.  This means I am going to have to handle moving data in 2 cycles for any given 16-bit move.  Effectively every 16-bit register will be handled as 2 8-bit registers.

Now, consider for example the need to move a new value into the Memory Address Register from Memory or a new value into the Program Counter from a Program Counter offset (i.e.: an immediate address value).  In both of those cases, the register providing the base address gets corrupted before the instruction can be completed.

To get around this concern, this computer will require a Temporary Register to assemble values for the Program Counter and the Memory Address Register.  Once the value is assembled properly, the Temporary Register can be copies (2 clock cycles) into the target register without corrupting its value during the critical load phase.

Therefore, all registers (including the Program Counter, since it is nothing more than a special-purpose register) are going to need to interact with the bus in 2 parts: the upper half and the lower half.

I looked, and there is no 74LS* 16-bit binary counter.  There isn't even an 8-bit binary counter.  The only thing I have to work with is a 4-bit binary counter (74LS161).  I am going to need 4 of them and I have none in stock.  It will be a week or two before I can get more.

Now, at some point in the future, I may convert this computer into something with a 16-bit bus.  When I do, I will have the ability to connect the 2 halves of the 16-bit register into separate halves of the bit and then redo the microcode to output both halves at the same time.

I'm bouncing around a bit today, but I get that luxury in my journals.

---

### 2022-Jan-24

Digging a little more into what the Program Counter requires (all lifted from the original computer), there are the following basic requirements (apart from the fundamental counting requirement):
* Enable/Disable the counter from the Control Module
* Able to jump to an address on the bus
* Reset the Program Counter on reset or power up
* Output the Program Counter to the bus
* The Program Counter will also make use of the Clock

Taking each of these in turn for a design discussion:

**Enable/Disable the Counter**

The Enable Common Interface line will be used to enable the counter.  It wll be handled by the Control Module in the final computer.  Both the upper and lower board will be tied together with the same Enable Control Line -- allowing all 16 bits to be counted.

This is an active high signal and will be routed to Pin 10 of the least significant nibble (Enable<sub>T</sub>).  Enable<sub>P</sub> will be tied high for all chips.

The Ripple Carry Output (Pin 15) will be carried into the Enable<sub>T</sub> for the next most significant nibble.

**Jump to an address on the bus**

This will have to happen in 2 cycles -- 1 for the lower byte and one for the upper byte.  As a result the source of the jump target will need to be built in and sourced from the either the Memory Address Register or the Temporary Register, depending on the instruction requirements.  This will be controlled by the Input Control Line from the Control Module.

This is an Active Low signal, so a 74LS04 Inverter will be required to properly prepare this signal for use.

**Clear on Power Up or Reset**

The Clear Common Interface point will be asserted on Reset or on initial power up.  The purpose is to reset all the 74LS161 chips to 0.  Both the Upper and Lower Modules will be tied together with a single Clear signal.

This is an Active Low signal, so a 74LS04 Inverter will be required to properly prepare this signal.

**Output the Program Counter to the Bus**

This will use the Output Control Common Interface line.  It will output either the lower byte or the upper byte to the bus.

The 74LS245 Transceiver is bidirectional, so it can move A->B or B->A.  I was hoping I would be able to eliminate 1 chip.  However, it looks like I will not be able to do that with the 74LS245 alone; additional chips would be required to separate the connections.  As this point, the 74LS245 is the better option.  I may revisit this if I get a spark of inspiration.

In the meantime, the 74LS245 has an Active Low enable line, so a 74LS04 Inverter will be needed to properly prepare the signal.

**Clock**

The Clock signal will be an input into this module.  It's signal will drive when the counter increments.  It will need to be routed to all chips.

---

The component count then is as follows:
* 4 X 74LS161 (8 pins wide)
* 2 X 74LS245 (10 pins wide)
* 2 X 10-bar LED graph (10 pins wide)
* 1 X 74LS04 (8 pins wide)

This is a very doable layout for 2 breadboards.  It will not be overly dense.

---

### 2022-Jan-26

Well, I had a problem with the original breadboard computer.  The problem is relevant here.  The situation was that the counters were counting when they shouldn't (i.e. the clock was in manual pulse mode), particularly the Program Counter.

I pulled the 74LS161 chip off and set up a dedicated test.  The problem was that somehow the clock line was picking up some noise and would force the 74LS161 to count even if the clock was switched to manual mode.  To make matters worse, the diagnostic tools did not work:
* The logic probe would not pick up any sort of pulse.
* The voltage meter would not show any kind of voltage.
* The oscillator when hooked up to measure it would eliminate the rogue signal.

Finally, I was able to determine that a 100Ω pull-down resistor across Pin 2 of the 74LS161 fixed the problem.  It would not work if it was placed on the clock module -- it had to be at the 74LS161.

I am running a test while I am writing this up, but things look promising on this front.  This is also something I will need to take into account for this design as well.

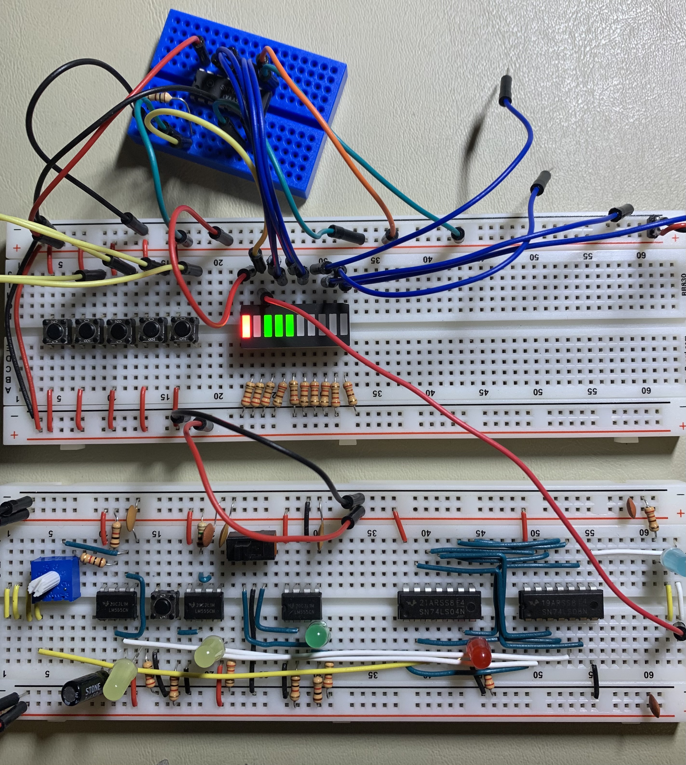
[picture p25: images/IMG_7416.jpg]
Testing the 74LS161 IC


In the meantime, if you look closely at the blue breadboard, you will see a resistor stuck in there for testing purposes.

---

I did manage to get a dry layout today for the Program Counter:

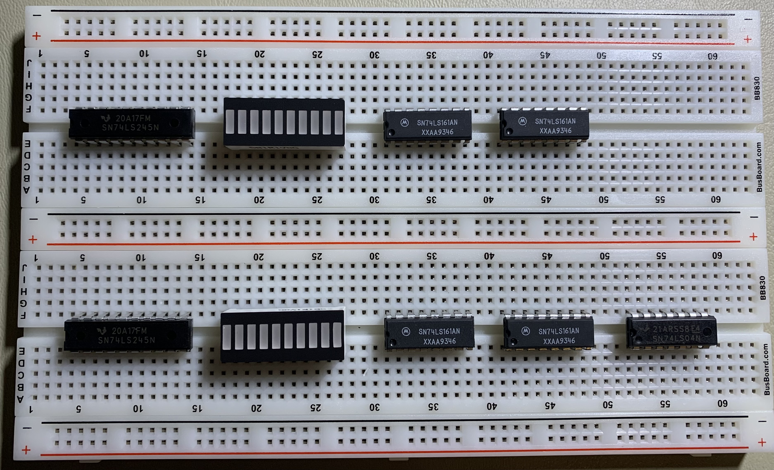
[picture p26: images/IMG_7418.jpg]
Program Counter Dry Layout


From left to right on the bottom board:
* 74LS245 (Buffer)
* 10-LED graph
* 74LS161 (4-bit counter)
* 74LS161 (4-bit counter)
* 74LS04 (Inverter)

The top board mimics the bottom with the exception of the 74LS04 Inverter.

This module will appear in the top-right corner of the layout overall.  Therefore, the buffer (and the bus) will be on the left of the module.  This means the clock lines appear on the left.

The layout is really just a little tighter than I wanted.  But the LED graph makes up for it a bit -- those would be twice as wide with regular 3mm LEDs.

I also calculate that I need to use 5 of the 6 inverters:
* Clear (will drive all 4 74LS161 ICs with 1 signal)
* Upper Load (JMP)
* Lower Load (JMP)
* Upper Output (for Instruction Register load)
* Lower Output (for Instruction Register load)

Now, I cannot get over whether I can use a single 74LS245 IC for both bus outputs.  I could but I would also need to replace 1 74LS245 with 2 74LS157 chips.  That is not a good trade-up.  At this point, I am not going to pursue getting fancy with it.  Whatever I do will probably end up costing me more ICs than the current layout.

---

### 2022-Jan-27

I realized that I had my personal notes incongruent with the [Readme.md](../Readme.md), and my own notes were not correct.  I updated my notes to match this project documentation.

I was able to get a couple things done on the Program Counter throughout part of the day today.  I started with seating all the ICs and wiring up the common interfaces.  Both the clock and the clear signals are bridged across power for the entire module.  I also added all the current-limiting resistors for the LEDs.

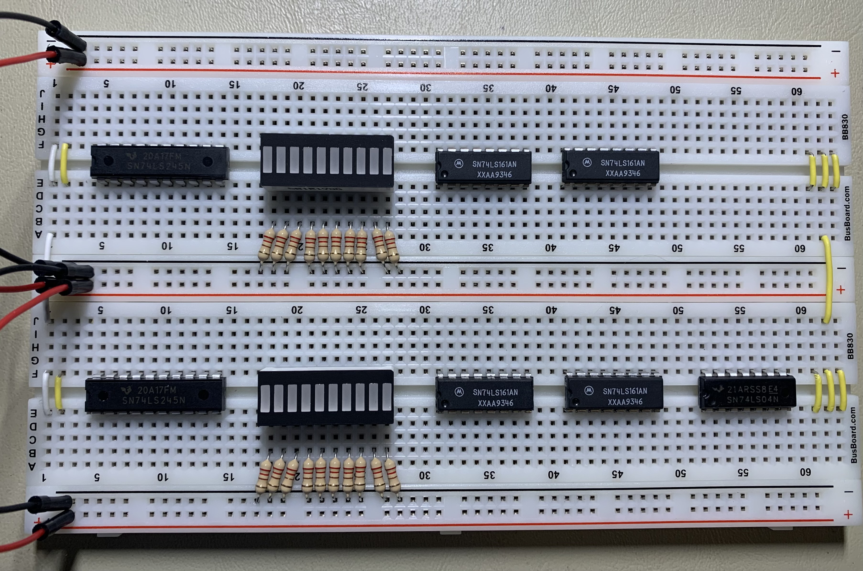
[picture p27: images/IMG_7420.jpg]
Starting the Program Counter


From there, I got into testing the counter and determining what would be required for wire-up.

---

I did a temporary wire-up for testing.  It turns out I had to add that 100Ω pull-down resistor to this board as well -- something I was actually expecting.  What shocks me is that I only had to wire it to the least significant nibble.  Since the other chips have the Enable<sub>T</sub> wired to the previous chip and the least significant chip is wired high, this does not appear to be a problem with the other 3.  So, 3 of the 74LS161 chips are wired similarly whereas 1 of them is different.

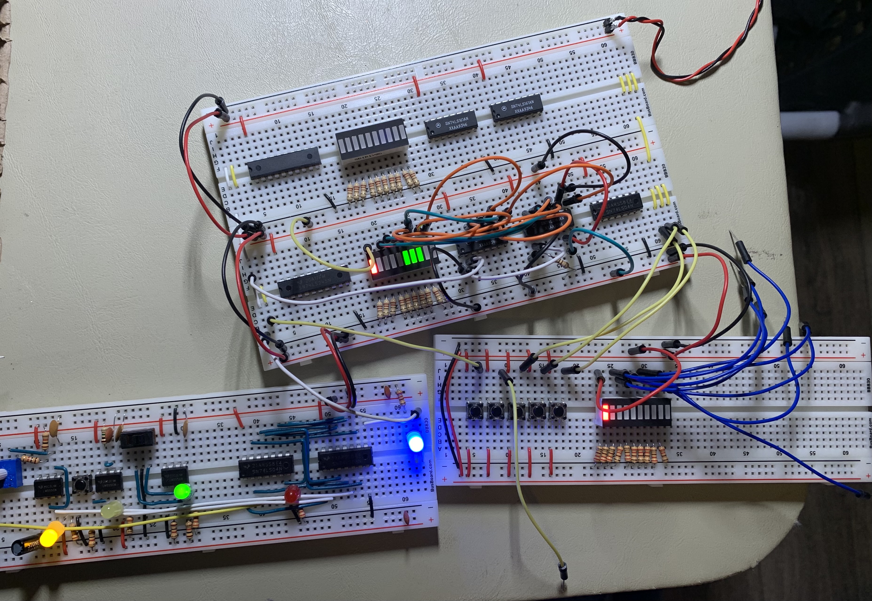
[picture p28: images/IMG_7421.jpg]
Temporary Wire-Up for Testing


Now, I just realized that the Enable Control Line needs to be bridged over the power rail as well.  This is because both the upper and lower counters will be enabled as a module.  I will catch that in the initial permanent wire-up.

The other thing I realized was that I crossed the chips, where the least significant data was located on the right whereas the for the LEDs the least significant data is on the left.  That also needs to be straightened out.

So, I will end up pulling it all out and starting over and working 1 chip at a time and testing as I go.  The least significant bit needs to remain on the right in all cases.

---

Well, except for the connections to the bus (which I do not have yet), I was able to get the lower Program Counter wired up this evening.  I think it looks much better than my work on the original computer.

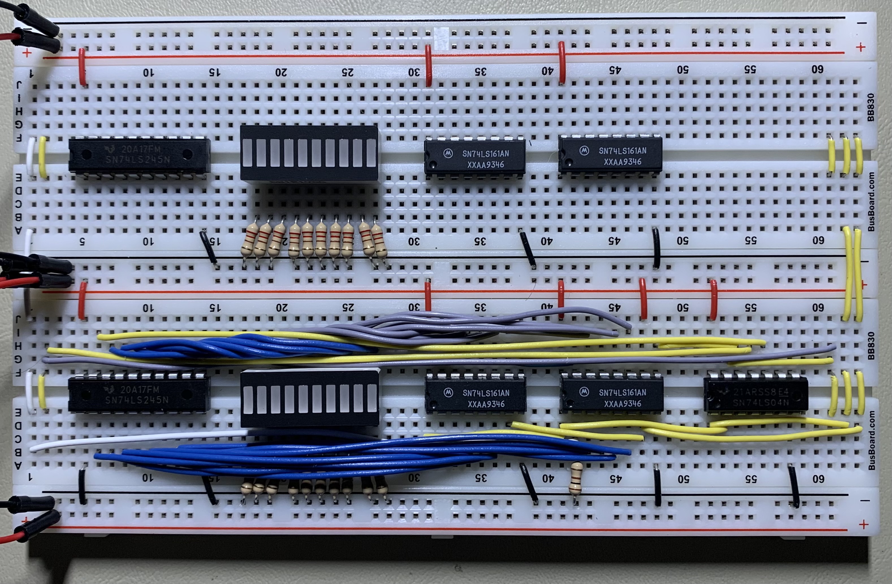
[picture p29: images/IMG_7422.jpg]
Lower Program Counter Wired Up


The connections to the bus for this section will be handled from the bottom left of the lower board.

I ended up having to add 100Ω pull-down resistors on the test harness as well.  I need to get those cleaned up and set properly (which I may try to accomplish at some point in the day.

---

### 2022-Jan-28

I was able to complete the Program Counter Module wire-up today.  I have tested most of it and it is at least counting properly.

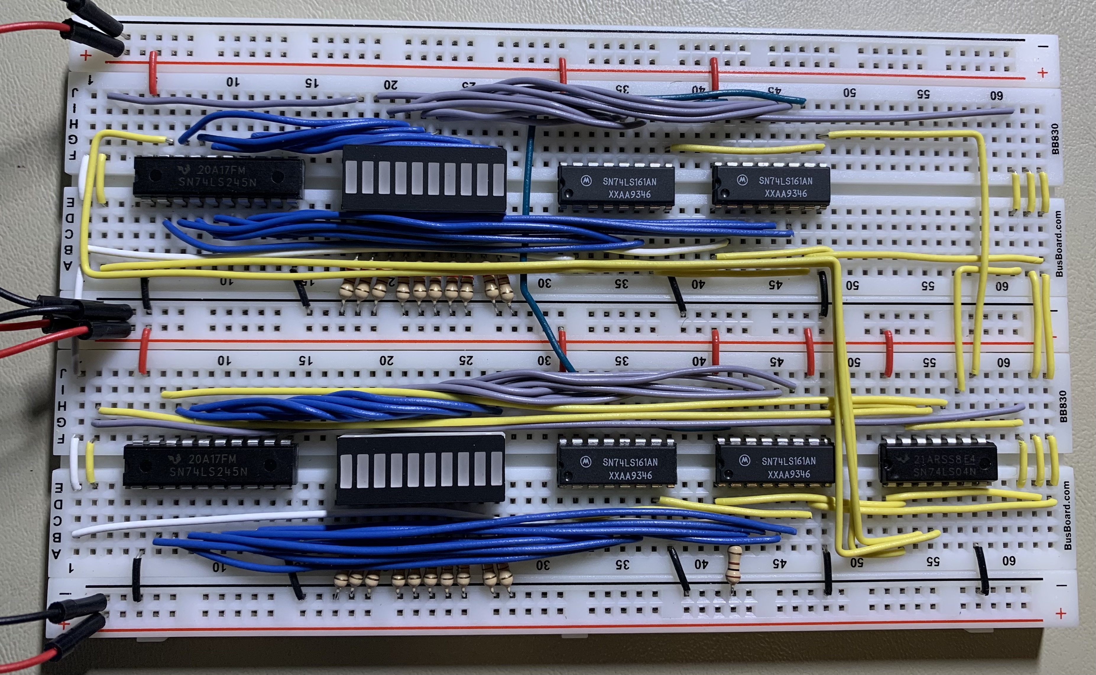
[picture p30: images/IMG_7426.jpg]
Wire-up Completed


If you would like to see the Program Counter in operation, you can see that [here](../images/IMG_7430.MOV).

I do still have a lot of work to complete on this module.  Still outstanding are:
* Test loading an address from the bus (confirm the bit order is correct)
* Test outputting an address to the bus (confirm the bit order is correct)
* Create the schematic

In the meantime, I am going to commit what I have so far (I want to check the video works on GitHub).

---

OK, now to get into the extended testing.  If I need to make any wiring changes I want to do that before I document anything.

Everything tested out properly.  I'm good to document the Module.

---

Well, I'm having a hell of a time getting everything to fit on a single sheet of paper.  The bus is particularly hard to deal with.  Not that I want to, but I may need to split the module into 2 schematics.  On the other hand, I may be able to notate the bus better and save a crap-ton of room.

---

### 2022-Jan-29

I was able to finish up the schematic today.

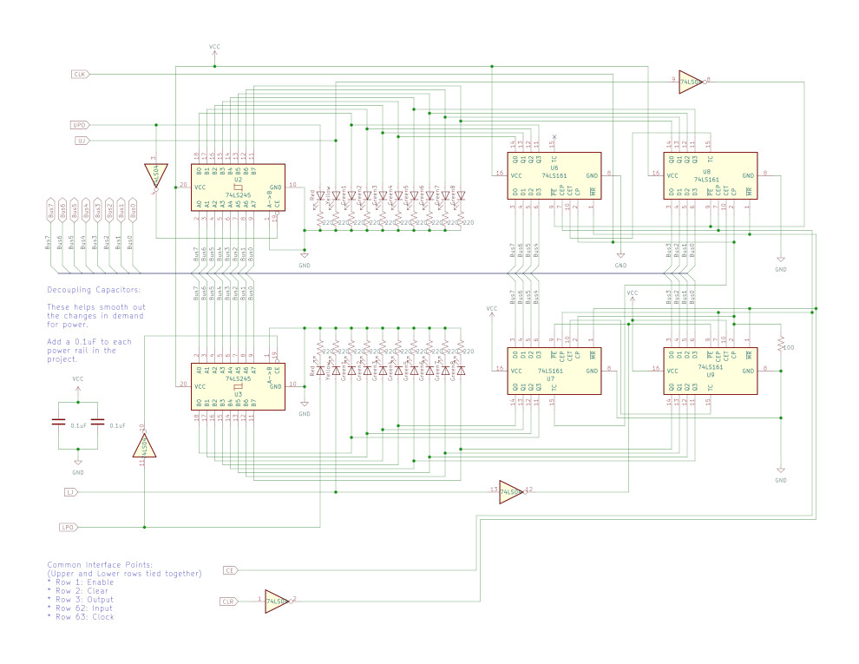
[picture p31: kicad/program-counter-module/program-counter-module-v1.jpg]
Program Counter Schematic


With this, I think the Program Counter module is complete.

Let me commit all this and then I will move on to the next module.

---

After committing the schematic, I found an error in the pin-out text at the bottom left.  It was reversed.  I have not updated the picture in this journal; just know it was wrong.

---

### 2022-Mar-19

Today I am going to come back to the program counter.  The purpose is to rename the files and perform some cleanup.

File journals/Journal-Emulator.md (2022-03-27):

# Breadboard Computer v2

This project is related to building hardware more than a software project.  There will be some code added to this project later on for programming the firmware and downloading a program, but that will be in the final stages.

This project is inspired by [Ben Eater's Breadboard Computer](https://eater.net/8bit).  Currently as this get started, I have his computer nearly complete and I am working on the final connections and debugging before I get into the control logic.

As usual with my personal projects, I am compelled to keep a journal of this progress.  As usual with my journals, I will not go back and edit anything historical as these are my continuing thoughts rather than documentation of the final product.

## Computer Emulator

This journal documents the journey I take to implement an emulator for the computer I am building.  This emulator will faithfully reproduce how the real computer behaves.

---

### 2022-Feb-28

Well, I have quite a bit of ADD lately.  I am going to start to kick around building out an emulator.  I do not expect to have much to add to the repo for a while, and in fact I am going to explicitly ignore the source when checking things in for a while.

I am working determining a framework and language for this development.  For the moment, I am working on Qt6 for the framework and Python3 for the language.  To solidify my choices, I will be doing some testing -- likely to build out an emulated clock module.

---

### 2022-Mar-03

Well, I have been playing around a bit with the Python code for the emulator.  I am getting some things done, which is nice.

First, there is something with PyQt6 which is not really working the way I want it to.  I am reverted back to PyQt5, which seems a little more solid at the moment.

I was also able to get a rudimentary timer timer working to the point I can manually (via changing code) set a timer frequency.  None of this was done on this computer, though.  So, I want to work on getting this code settled into this project.  It's kinda dead-head stuff at the moment, so it is nice for me to work on it while I let the last wire-up job bake in my head.

The first order of business is to get the LED working properly.  I have a round one nearly complete, so I will work on getting that moved over.

I was also able to pull a sliding switch object from stack overflow.  So, that piece is set to work as well.

So, I should have nearly everything I need to get the clock module assembled, which I can work on over the next few days.

---

### 2022-Mar-04

Today, I was able to get the basic layout completed for the clock module.  Not everything is displayed yet, but it is workable.

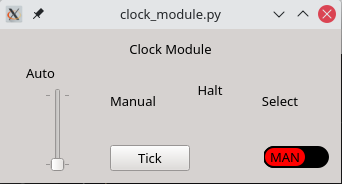
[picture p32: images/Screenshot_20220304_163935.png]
Clock Module


The next thing is going to be to figure out how to wire up the signals and slots.

---

I am having problems with the updates from the clock signal to the LED.  Python is seg-faulting when I try to change the frequency.  I believe this is a problem with the design and needing to get signals and slots working properly.  Not starting the thread solves the problem.

---

### 2022-Mar-05

I think I need to get a label which shows the current clock speed setting.  It will be a good way to play with signals and slots before I get into the task running again.

Well, I have the actual clock running, with a selectable frequency from 1 to 25 Hz.  Not bad for this emulator.  It is able to step by single (1 Hz) increments.

The next thing will be to set up the manual single-step clock to work.  After that, I will have to set the final clock output to be handled properly.

---

### 2022-Mar-07

Well, I gave up on the Python Qt code and deleted it in total.  I am going to work with a C++ version with Qt6.  It is coming together far faster with their tools and so far I am writing very little code.  I will need to figure out how to merge the code from a separate VM into this base where they are not allowed on the same network.

---

### 2022-Mar-11

I think I am going to work on some of the low-level components I need for the emulator.  Specifically, I think I will work on getting the round LED working such that I can use it in Qt Designer -- which would be nice.

OK, I need nothing on the LED widgets for the emulator; there is an LED already included in QtCreator!  So, I only need to be concerned with the slider if I am going to use that.  I can also use just a checkbox to accomplish the same thing.  So, I should be good.

---

I have the layout of the emulator established.  The clock module is laid out:

Emulator Clock Module

Before I get too much farther, I need to establish some back-end threads for handling the different conditions.  For example, the Timer LED needs to flash no matter what; the Manual LED needs to come on for about half a second and then go back out.  And the clock LED needs to be triggered on either of the other 2, but also needs to be conditioned on the value of the Run checkbox.

This probably means I am going to need to subclass several of these sections or perhaps just have a background class which manages all this.

While I think about this, I will work on the hardware.

---

### 2022-Mar-13

I got the clock module completed in the emulator.  It actually works well.  The only limitation is the speed of the clock, which is capped at 25Hz in the emulator.

I actually believe this is enough of a change that I should commit the code even if I do not have the proper documentation on what needs to be installed.

---

### 2022-Mar-14

It occurs to me that I really need to get parts of the control module set up so that I can simulate actions and test things out as I go.  This will emulate what I have going on with the physical build as well.  At some point, I will need to work out exactly how to have 1 set of binary data which will write to both the EEPROM and be used by the emulator -- when you have 2 masters, 1 is guaranteed to be wrong!

Anyway, the control module really should be started to get some things working like the real world.

---

I was able to get all kinds of stuff done today.  I was able to get several control signals built:

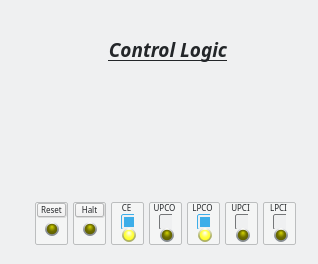
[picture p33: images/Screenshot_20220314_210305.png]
Control Module


I was able to get a program counter working properly (and I believe it is complete):

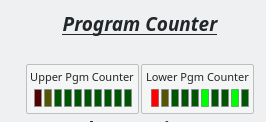
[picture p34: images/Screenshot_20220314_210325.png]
Program Counter


Finally, I was able to also get a bus set up so I can pass data back and forth:

Bus

All-in-all, things were rather productive today!

---

### 2022-Mar-15

Today I was able to get the Temporary Register 1 and 2 both working today.  I was also able to create a more generic register from which each register is sub-classed.

I currently have a problem whereby I am creating a class (not just an object, but a separate class) for each register.  I could clean that up, but my intent is not to write the cleanest code here.

Instead, my intent is to get an emulator working so I can write the BASIC code and start testing that out on an emulator before committing it to the hardware.

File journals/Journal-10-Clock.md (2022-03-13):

# Breadboard Computer v2

This project is related to building hardware more than a software project.  There will be some code added to this project later on for programming the firmware and downloading a program, but that will be in the final stages.

This project is inspired by [Ben Eater's Breadboard Computer](https://eater.net/8bit).  Currently as this get started, I have his computer nearly complete and I am working on the final connections and debugging before I get into the control logic.

As usual with my personal projects, I am compelled to keep a journal of this progress.  As usual with my journals, I will not go back and edit anything historical as these are my continuing thoughts rather than documentation of the final product.

## Clock Module

The first module to build is the Clock Module.  It will be required for nearly every other module that will be built.

---

### 2022-Jan-21

I got started with a second Clock Module today.  I started with the bi-stable timer.  It was not working (or so I thought) until I realized I ordered 10K Ohm variable resistors instead of 1M Ohm ones.

---

### 2022-Jan-22

OK, so I admit I am starting this Journal today.  I back-dated yesterday's entry since that was what I worked on yesterday and overnight I decided to create this Journal.

Today, after getting the Journal started, I worked on a board for testing.  Part of this was done yesterday and I completed it today.  Here is a picture of the near-complete board:

Test Board

This test board was built on a BB830 breadboard.  However, today I ordered several BB400 breadboards and will migrate this to the new smaller board when they arrive.

---

For the Clock Module (Clock or Timer?  They are "timer" Integrated Circuits, but the intended output is a regular clock signal, so I am going to refer to it as a Clock Module), I ordered the replacement potentiometer (or variable resistor) today.  Well, a number of them.  I can pull the original one if I need to test something, but I will likely be working and documenting as much as I can before they arrive.

I also have plenty still to do for the original computer.

---

Before I go there, the Clock Module has a 74LS32 OR-gate used.  Only 1 OR gate.

I think I recall from my Boolean Algebra that I can replace OR logic with inverted inputs with AND logic.  Something like this:

`A | B = (A' & B')'`

So, let's set up a truth table to see if I am lying.

| A | B | A' | B' | A' & B' | (A' & B')' |
|:-:|:-:|:--:|:--:|:---:|:---:|
| 0 | 0 | 1  | 1  | 1 | 0 |
| 0 | 1 | 1  | 0  | 0 | 1 |
| 1 | 0 | 0  | 1  | 0 | 1 |
| 1 | 1 | 0  | 0  | 0 | 1 |

So, I can replace the single OR gate with 3 additional NOT (inverters) and 1 additional AND gate.

The 74LS08 is a Quad-AND gate IC.  I am using 3 of the 4 currently, so there is 1 available.  I need 1 and this will use the entire capacity of this chip.  Nice and efficient.

The 74LS04 is a Hex-Inverter IC.  I will be using 2.

***Note:*** *Ben Eater's Clock Module also outputs the inverse of the clock signal which is used only by the Control Module.  My plan is to invert this signal on the Control Module since it will better be represented by the Common Interface I am planning to put forward.  This plan saves me an inverter and a long signal line around the boards.*

This will leave 4 available inverters.  I need 3 inverters for this changed logic, leaving 1 unused gate.

Overall this change saves me 1 IC chip.  This feels like an appropriate improvement, since the power will be a concern with the number of chips in this computer.

---

I wired up the monostable (de-bounced) circuit on the new Clock Module.  They are not yet connected so the circuits work independently.  Here is the progress so far:

2 timer circuits

The LED lights are there to indicate the clock pulse for each circuit and will remain on the final board.

---

I now have all 3 timer circuits built.  They are not connected yet.  This (generally speaking) is all the analog circuitry that will be built into the computer (with the exception of the output display).

3 555 Timer Circuits

The 3 LED lights are (from left to right):
* The astable timer (flickering quite fast since I still have the incorrect variable resistor).
* The monostable timer, activated by the push button to the left.
* A green LED to indicate that the timer is in run mode.

The next step will be to hook up the logic circuits to output the correct clock signal and halt the clock with the proper control signal.

Connecting the logic was quick for a temporary wire-up.  The Clock Module tests out properly.  The sliding switch properly selects between the astable and monostable timer circuits, with the green LED on when the Clock Module is in run mode.

Temporary Wire-Up

Assert the Control Line

This is a very successful test and the only thing left at this point is to replace all the temporary wires with proper cut-to-length wires and clean up the LED and resistor lengths.

---

Now that it is all cleaned up, here is the board:

Cleaned up Clock Module

I am able to halt the clock.  Notice the interface point has been extended to the proper location on the board (the yellow wire).

Cleaned up Clock Module

Also, with the Clock Module in single-pulse mode (the sliding switch now to the left), I am able to manually trigger a clock pulse.

Cleaned up Clock Module

---

This actually completes the updated Clock Module.  These updates accomplish the following:
1. Remove an IC and better utilize the remaining ICs.
2. Create Common Interface Points on the module, which will match every other module built.
3. Added some additional indicator lights for the module state, including halted by the Control Logic.

I also added a current-limiting resistor to the blue LED which is driven from the 74LS08.  Ben Eater does not use them in the videos.  I will.  I have burnt a few LEDs and ICs.

That said, the LED specs state that the current forward is 20mA and the voltage forward is 3.5V.

LED Specifications

The data sheet for the 74LS08 states the max output current (I<sub>OH</sub>) is 0.4mA.

74LS08 Data Sheet

0.4mA is certainly less than the LED's limit of 20mA.

Now, this is not to say that I have read and interpreted all these data points properly.  In fact, I would bet I have not.  I never claimed to be a professional.  Or an expert.  I'll use the resistors, thank you very much.

---

### 2022-Jan-23

After the first commit, I decided to separate my journals into each module and place them into a separate folder.  As a result, I had several links to clean up.

---

I was able to find KiCAD, which is open source.  I downloaded version 6.0.1 and installed it on my system.

From there I was able to create a schematic of the Clock Module and export that to a .jpg as well.  Here is the result:

Clock Module Schematic

The base schematic is the same as the original.  I was specific about which LEDs I added and added instructions on how to set up the common interface points.

---

### 2022-Jan-24

I did find some errors in the schematic (things like connections not completed).  I cleaned those up today and re-published the above image.  That said, I also had to update my naming convention so I can keep them separate.

---

### 2022-Feb-25

Today I am going to rename a few things to conform to the proper naming standards.  This will include this Journal and the schematic drawings.

These changes give me the following schematic now:

Clock

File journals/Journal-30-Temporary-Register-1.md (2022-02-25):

# Breadboard Computer v2

This project is related to building hardware more than a software project.  There will be some code added to this project later on for programming the firmware and downloading a program, but that will be in the final stages.

This project is inspired by [Ben Eater's Breadboard Computer](https://eater.net/8bit).  Currently as this get started, I have his computer nearly complete and I am working on the final connections and debugging before I get into the control logic.

As usual with my personal projects, I am compelled to keep a journal of this progress.  As usual with my journals, I will not go back and edit anything historical as these are my continuing thoughts rather than documentation of the final product.

## Temporary Register 1

This register is going to handle the upper part of the ALU calculations.  There are 2 inputs to the ALU which will be Temporary Register 1 and Temporary Register 0.

The key here is that the former A Register (documented so far in the [A-Register Journal](Journal-A-Register.md)) has been repurposed to be Temporary Register 1.  And now I have bugs to correct, which will be addressed from here.

### 2022-Feb-18

Somethings things just don't work out the way you want them to.  This bug is keeping me from properly testing and wiring up the ALU.  I guess I need to accept that it is better to have found this now rather than after the wire-up.

---

I need to start by figuring out where the problem is with the wiring.  I believe it is in the input from the bus, but I need to concretely confirm it.

Well, I was able to confirm it and I was able to get it cleaned up.  Now, at least the Lower Temporary Register 1 is working as it should.

---

### 2022-Feb-19

Well, I might have had to correct and then re-wired it to be incorrect last night.  I know I am certainly wiring things backwards at the moment.

Well, after some looking and re-wiring, it was correct.

---

OK, now the Upper Temporary Register 1 wiring is not correct.  I think it has the same problem as the Lower T1 had.  I got that worked out.

---

### 2022-Feb-20

This file has been renamed to represent its location in the overall computer.

---

I have the Upper Temporary Register 1 schematic completed.

Upper Temporary Register 1

... and through the magic of copy-and-paste, I have the Lower Temporary Register 1 schematic completed as well.

Lower Temporary Register 1

This, then, allows me to clean up the old folder (which will need to have its image moved).

Ahhhh....  I missed the connections to the actual ALU.  These will need to be added and the schematics re-published.

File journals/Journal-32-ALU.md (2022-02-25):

# Breadboard Computer v2

This project is related to building hardware more than a software project.  There will be some code added to this project later on for programming the firmware and downloading a program, but that will be in the final stages.

This project is inspired by [Ben Eater's Breadboard Computer](https://eater.net/8bit).  Currently as this get started, I have his computer nearly complete and I am working on the final connections and debugging before I get into the control logic.

As usual with my personal projects, I am compelled to keep a journal of this progress.  As usual with my journals, I will not go back and edit anything historical as these are my continuing thoughts rather than documentation of the final product.

## Arithmetic Logic Unit (ALU)

The ALU is used to perform lots of basic functions on the CPU.  It does..., well..., arithmetic and logic work.

Since I am going to need the ALU for memory management (and since I have abandoned the Memory Module and A Register for the time being), I am going to shift gears to the ALU.

---

### 2022-Feb-11

OK, this is going to take some work and analysis.  Not everything in the ALU documentation makes sense.

First there are 16 bitwise operations that can happen.  After seeing [this section](https://en.wikipedia.org/wiki/Bitwise_operation#Truth_table_for_all_binary_logical_operators), I vaguely remember them all.  There are some obscure ones.

Wikipedia's Bitwise Operators Table

Now, compare this to the 74LS181 data sheet, and these are the operations I should expect to be able to do:

ALU Operations

There is a whole lot of what the huh???!?!!

To be clear, I am working with active-high values.  So, this means I need to have the carry-bit set to get my Arithmetic operations to work properly??!?!

The problem I have is that the 74LS181 data sheet does not properly document the logic functions.  Take NOR for example:

NOR

That really should have the bar over the whole expression since it is the inversion of an OR, not the inversion of A OR'd with the inversion of B (as the data sheet would imply).

But, through some experimenting with the 74LS181, I was able to confirm that the function was really NOR.

So, between the logical and arithmetic functions, here is what I want to support:
* NOT
* AND
* NAND
* OR
* NOR
* XOR
* XNOR
* FALSE (or 0)
* TRUE (or -1)
* ADD
* SUB
* SHL (Shift Left 1 position or multiply by 2)
* INC
* DEC
* NEG (really: 0 - A)

I also want to be able to support ADC and SBB if I can work it out.

So, time to make a table of the pin configuration for each operation:

| Oper  | S3 | S2 | S1 | S0 | M | Co | Inv |
|:-----:|:--:|:--:|:--:|:--:|:-:|:--:|:---:|
| NOT | L  | L  | L  | L  | H | L  | x |
| AND | H  | L  | H  | H  | H | L  | x |
| NAND  | L  | H  | L  | L  | H | L  | x |
| OR | H  | H  | H  | L  | H | L  | x |
| NOR | L  | L  | L  | H  | H | L  | x |
| XOR | L  | H  | H  | L  | H | L  | x |
| XNOR  | H  | L  | L  | H  | H | L  | x |
| FALSE | L  | L  | H  | H  | H | L  | x |
| TRUE  | H  | H  | L  | L  | H | L  | x |
| ADD | H  | L  | L  | H  | L | H  | Inv |
| SUB | L  | H  | H  | L  | L | L  | No  |
| SHL | H  | H  | L  | L  | L | H  | Inv |
| INC | L  | L  | L  | L  | L | L  | Inv |
| DEC | H  | H  | H  | H  | L | H  | No  |
| ADC | H  | L  | L  | L  | L | c' | Inv |
| SBB | L  | H  | H  | L  | L | c  | No  |

That is 16 operations.  In the operation selection, there is a Carry-In component (making 32 distinctions) and a Carry-Out component driving the arithmetic.

So, if my inputs are 5 bits (4 control lines plus the carry flag) the output should be able to be the 6 bits above.  I should be able to handle that with an EEPROM.  That will actually work quite nicely.

I actually think I will need a control signal to invert the carry flag on output as well.  I have room for that so I will have no problem adding it.  So, that is 6 output bits.

So, this is all with a simple 4-bit ALU.  Next I will need to hook up a second one and attempt to perform the same functions with 2 ALUs.

---

### 2022-Feb-12

Once I started to hook up multiple ALUs, I ended up seeing the carry output behave properly.  So I may not need to invert that output.  I want to wire up the whole ALU to check again.

ALU Testing

Now, the ALU is not dependent on the clock.  The ALU only has the output standard control line.  The other control lines will be the 4 control lines to select the ALU operation.

I do have 2 registers (both will be re-branded to be temporary registers) that are prepared for adding into the ALU.  I will only need to save room for the flags register.  I anticipate 2 boards for that.  But this is about the ALU.

The ALU is going to require 3 boards.  One for the upper ALU, one for the lower ALU, and one for the control logic.  I will need an inverter to handle the carry bit inversion and an AND gate to merge the `A=B` lines.  I think I can move the `A=B` merge onto the flags module.  So, that will leave an inverter and just the EEPROM for the control logic.

Ahh...!  But I also need to place a 74LS245 to control the output to the bus.  This also needs a control line.  This now makes things crowded and 3 board will be a requirement.

OK, here is the ALU "dry" layout.

"Dry" Layout

Notice the empty space in the center board to the right-hand side?  That is for the EEPROM which I need to order.  I will order that on Monday (since they do not ship over the weekend) and should have that by Wednesday.

---

First up is the foundational wire-up.  To that, I will add 4 control lines to the center board for the function selection.

---

That completed, I now need to start wiring up the control lines.  The 2 output lines need to be inverted.

---

I was able to get the Lower Temp 2 Register (stand by for the story on that one) hooked up.  It is not right.  I'm going to have to do some tracing to see where things went wrong.  But, I really don't think I have that in me tonight.  It was in the 90s here today and I did some work outside.  I am beat and can't really think clearly.

---

### 2022-Feb-13

I actually figured out what I did wrong last night (away from the breadboards).  I hooked up the wires to the wrong pins (well, duh!).  I neglected to confirm which pins wer A pins and which were B pins, so I simply put them all in line.  Actually, they alternate A and B pins, so I have them crossed.  This should be trivial to confirm.

The Instructions

In the picture, you cal clearly see that pins 21 & 22 are both hooked up (pin 23 is also hooked up but under the other wires in this photo), and should not be since I was only wiring up the B pins.

Which Were Not Followed

A quick adjustment and the "B calculation" result is passed along to the ALU output.

ALU Result is the "B" Input

---

Well, I just realized that I am going to run out of green hook-up wire before I get the ALU wired up.  This is going to suck as I will need green wire for any module I want to work on if I am going to stick with my wire-theming.

---

After getting the Temp 1 Lower wired-up with temp jumpers, I was able to confirm that that table appears to be correct at least for 8-bits.

---

I think I am going to move the 74LS04 and 74LS08 chips over to make room for a second EEPROM IC -- just in case I want to add some additional actions (most likely which flags will be updated by any given operation).

---

### 2022-Feb-14

OK, I got my supplies order out today.  I hope to have it by Wednesday.

In the meantime, I am working on how to determine equality.  The 74LS181 is supposed to have an `A=B` pin, but I am not able to determine what that is all about.  Even the schematic does not make sense.

So, my thought is to check the ALU output (all 16-bits) to see if they are all 0.  This will allow me to create opcodes like CMP which will do the subtraction but not update any registers and TEST which will do an AND but not update any registers.

To do this check a NOR gate will work well to compare pairs of bits.  I will need 8 gates to compare 16 bits, which is on 2 74LS02 chips.  Then all 8 outputs will need to be ANDed together (another 7 AND gates or 2 74LS08 chips) to get the final Zero Flag output.

On top of this, I need to control the inversion of the Carry Flag which will be controlled in the ALU Control Code.  And I have not even started to figure out < or > logic and store those bits.  However, the ALU is slowly getting bit enough to warrant considering moving that to a third column of boards in the overall layout and to "bridge" the bus between them.

So, taking into account what I might have built already, what could this look like?

| Left Column | Center Column | Right Column |
|:---:|:---:|:---:|
| Clock Module | Upper Program Counter | Upper Temp 1 Register |
| Upper MAR | Lower Program Counter | Lower Temp 1 Register |
| Lower MAR | Upper Flags | Upper ALU |
| Upper RAM | Lower Flags | Lower ALU |
| Lower RAM | Upper Stack | Upper Temp 2 Register |
| Upper A Register| Lower Stack | Lower Temp 2 Register |
| Lower A Register | Bus Bridge | ALU Control 1 |
| Upper B Register | Bus Contents | ALU Control 2 |
| Lower B Register | CPU Constants | Control Logic 1|
| Upper X Register | Upper Output | Control Logic 2|
| Lower X Register | Center Output | Control Logic 3|
| Reset Logic | Lower Output | Control Logic 4 |

A couple of things I like about this layout better:
1. The flags register is actually closer to the ALU, which will be driving the flag updates.
2. The computer feels more square meaning I should not have to stretch too far to wire things up (or stand to do it for that matter).
3. This layout will work better with the size of the board I am building on (really just a side benefit).
4. Overall, this will modularize the ALU and is being treated more like a micro-controller than anything.
5. The bus bridge is about the same width as width as a breadboard without the rails, so it will be easy to integrate.

This, then brings me back to the ALU Control Logic.  I need room for:
* 1 74LS04 Inverter
* 2 74LS30 Quad 2-Input NOR Gates
* 3 74LS08 Quad 2-Input AND Gates
* 2 28C16 EEPROMs

This is 8 ICs on 2 boards.  It will be tight, but still doable.

Now to tackle this whole Carry Flag inversion mess:

| Carry In | Invert | Carry Out |
|:---:|:---:|:---:|
| 0 | 0 | 0 |
| 0 | 1 | 1 |
| 1 | 0 | 1 |
| 1 | 1 | 0 |

Well, that looks like a simple XOR gate and I should be able to replace one of the Quad AND Gates with an XOR Gate and handle that a little better.

So, I am down to 7 AND gates, 1 XOR gate, and 8 NOR gates.  I also need 2 Inverters.

Now, the next step is to plan how to separate the ALU from what has already been built.  More to the point, how to separate Temp Register 1 and the ALU from the rest of what has been built.  That sounds easier than it really will be.  I will also need to collapse the ALU and separate out the ALU Control Logic.

I'm almost starting over, but not quite.

---

Well, I feel like I just took apart and reassembled Frankenstein's monster.  Lots of little things needed to be removed, relocated and reconnected.

That said, I have a fully assembled ALU module (well, the breadboard are all physically connected).  The next problem is that it will not fit on the board anymore.  I will have to find something bigger.

I know Home Depot has 1" rigid foam insulation; I just need to make sure it will be the correct size.

OK, so now what?  I do not have everything I need to wire-up the ALU.  I do know I want to re-route many of my current connections.

---

### 2022-Feb-16

Late last night and so far this evening, I have been working on wiring up the ALU outputs to the LED lights and the 74LS245 Buffer.  I managed to get all the control lines routed together.  I also have the output common control lines routed to the ALU Control Board and then back up to the 74LS245 to enable the output.

I am basically killing time until I get my supplies order -- on Saturday!  Grrrr....

Now, on the other hand, I could probably start the firmware component which will drive the ALU Control Logic.  This is going to be written in and maintained in the Arduino IDE, but will be a directory in this project.

---

### 2022-Feb-18

OK, I did find a problem with the DEC functionality.  It was corrected and I think I have it working now for 1 bit.

I had several problems with the ALU wired wrong.  All of those have been corrected as well.

So, now I am left with a mess of wires to replace with wires that are cut to length.

ALU Dry-Wire

Trust me: the picture does not do it justice.

---

### 2022-Feb-19

Well, I wired up half the Lower ALU today and then realized I have it all backwards again.  I may have even had the Lower Temporary Register 1 correct yesterday before I changed it.

My problem appears to be the inability to distinguish between the most significant bit and the least significant bit properly.

I'm starting to get annoyed about the whole situation.

---

I need to stop second-guessing myself.  I pulled it all apart to realize that it was correct.

---

A quick code change for the ALU Controller EEPROM and the actual ALU is complete.  The only thing left are the gates to handle the flags analysis prior to handing them off to the flags register.

ALU Nearly Complete

So, there are a few orange and yellow jumpers on the right side, which are used for loading the Temporary Registers.  There are 2 single (blue and green) jumpers in the center of the left of the module which were used for testing to disable the output from the ALU.  Finally, all the remaining multi-colored jumpers along the left are for connecting to the bus, and will be cleaned up once I have a bus to connect to.

Finally, along the bottom are the logic gates I will need to complete the analysis for the flags.  I just need to decide which flags I will be doing.

In the meantime, it is time to commit this work.

---

### 2022-Feb-21

I moved several paragraphs from this Journal to the ALU Controller Journal.  This was done in the interest of the computer layout, aligning this Journal specifically with the ALU which resided between the 2 Temporary Registers.

At the same time, this Journal file will be renamed as well to align to the naming.

---

### 2022-Feb-23

Completing the ALU schematics today:

Upper ALU

... and:

Lower ALU

I was also able to complete the ALU Control Board:

ALU Control

---

### 2022-Feb-25

Today, I wrapped up the ALU schematics.  Board "38"
remains empty and I am not planning to write a schematic for an empty board.

ALU Flags

This should actually wrap up the ALU.  Until I find something I need to change.  Time to commit these changes.

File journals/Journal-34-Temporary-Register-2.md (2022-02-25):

# Breadboard Computer v2

This project is related to building hardware more than a software project.  There will be some code added to this project later on for programming the firmware and downloading a program, but that will be in the final stages.

This project is inspired by [Ben Eater's Breadboard Computer](https://eater.net/8bit).  Currently as this get started, I have his computer nearly complete and I am working on the final connections and debugging before I get into the control logic.

As usual with my personal projects, I am compelled to keep a journal of this progress.  As usual with my journals, I will not go back and edit anything historical as these are my continuing thoughts rather than documentation of the final product.

## Temporary Register

There are a number of registers that need to be built for this computer.  Several of them are going to look the same or will be built as mirror images of each other.  The most basic of these will be the Temporary Register, which will not be accessible from software directly.  It will instead be used by Microcode to assemble 16-bit values from a referenced memory location.

---

### 2022-Jan-30

Ben Eater used 74LS173 ICs for the registers, which used pins 9 & 10 to load the 4 bits.  I am going to use 74LS273 ICs to accomplish the same thing.  However, the 74LS273 registers will load a value on any clock pulse.  Therefore, I will need to AND the clock pulse with the Register In Control Line and then feed that result to pin 11 on the 74LS273.

Like the Program Counter, I am going to use the 10-bar LED graph to indicate the register contents, with the yellow LED to indicate input from the bus and the red LED to indicate output to the bus.

Otherwise, the layout is quite simple and not dense at all.

Temporary Register Initial Layout

This register will be on the right-side of the bus.  I will get the initial wire-up (common connections, power, ground, power limiting resistors) taken care of.

---

It took a couple hours to get to the point I had the upper byte wired up.  Here is a test of that half-register.

Testing Upper Byte

It did not take too long ot wire up and test the lower byte of the register.  This module came together and tested properly quick.  I think that's good because I have several to do.

Here is the complete module:

Complete Temporary Register Module

---

### 2022-Jan-31

Today I signed up for a course on https://corsera.org: **Linear Circuits 1: DC Analysis**.  This is going to slow me down a bit (but there are budget concerns as well, so slower will be better), but I will be better off for it I think.

I also want to get in the schematic for the Temporary Register.

---

### 2022-Feb-01

Here is the schematic for the Temporary Register.

Temporary Register Schematic

This should wrap up this module.

---

### 2022-Feb-11

Well, I had a but of an epiphany yesterday while I am out and about: Why am I worried about stupid optimizations when I need to be worried about getting this iteration completed.  As such, why do I need a MAR, MIR, MAA, and MAP when all I really need is a MAR and an ALU.  The same question goes for the stack: why do I need it when I can use the ALU?  Yeah, it may take an extra clock cycle or two, but I am going for the blinking lights more than I am going for speed.  If I want speed, I will buy another laptop.

So, I need to go back and revisit my work on the Memory Address Module (which will be torn down and redone), and the A and Temporary Registers (as they may be relocated and need to be flipped.

With that said, I am going paste this same update into all 3 Journals since they will all need to be revisited.

---

### 2022-Feb-20

This register has been renamed to be the second Temporary Register (actually Temporary Register 2).  As such, I need to update the schematics.  It has been incorporated into the overall ALU section of the computer.

---

### 2022-Feb-21

I renamed this file to match the new standard.

I am working on the schematics today.

Again, through the magic of copy-and-paste, I have the Upper Temporary Register 2:

Upper Temporary Register 2

... and the Lower Temporary Register 2:

Lower Temporary Register 2

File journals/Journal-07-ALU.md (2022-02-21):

# Breadboard Computer v2

This project is related to building hardware more than a software project.  There will be some code added to this project later on for programming the firmware and downloading a program, but that will be in the final stages.

This project is inspired by [Ben Eater's Breadboard Computer](https://eater.net/8bit).  Currently as this get started, I have his computer nearly complete and I am working on the final connections and debugging before I get into the control logic.

As usual with my personal projects, I am compelled to keep a journal of this progress.  As usual with my journals, I will not go back and edit anything historical as these are my continuing thoughts rather than documentation of the final product.

## Arithmetic Logic Unit (ALU)

The ALU is used to perform lots of basic functions on the CPU.  It does..., well..., arithmetic and logic work.

Since I am going to need the ALU for memory management (and since I have abandoned the Memory Module and A Register for the time being), I am going to shift gears to the ALU.

---

### 2022-Feb-11

OK, this is going to take some work and analysis.  Not everything in the ALU documentation makes sense.

First there are 16 bitwise operations that can happen.  After seeing [this section](https://en.wikipedia.org/wiki/Bitwise_operation#Truth_table_for_all_binary_logical_operators), I vaguely remember them all.  There are some obscure ones.

Wikipedia's Bitwise Operators Table

Now, compare this to the 74LS181 data sheet, and these are the operations I should expect to be able to do:

ALU Operations

There is a whole lot of what the huh???!?!!

To be clear, I am working with active-high values.  So, this means I need to have the carry-bit set to get my Arithmetic operations to work properly??!?!

The problem I have is that the 74LS181 data sheet does not properly document the logic functions.  Take NOR for example:

NOR

That really should have the bar over the whole expression since it is the inversion of an OR, not the inversion of A OR'd with the inversion of B (as the data sheet would imply).

But, through some experimenting with the 74LS181, I was able to confirm that the function was really NOR.

So, between the logical and arithmetic functions, here is what I want to support:
* NOT
* AND
* NAND
* OR
* NOR
* XOR
* XNOR
* FALSE (or 0)
* TRUE (or -1)
* ADD
* SUB
* SHL (Shift Left 1 position or multiply by 2)
* INC
* DEC
* NEG (really: 0 - A)

I also want to be able to support ADC and SBB if I can work it out.

So, time to make a table of the pin configuration for each operation:

| Oper  | S3 | S2 | S1 | S0 | M | Co | Inv |
|:-----:|:--:|:--:|:--:|:--:|:-:|:--:|:---:|
| NOT | L  | L  | L  | L  | H | L  | x |
| AND | H  | L  | H  | H  | H | L  | x |
| NAND  | L  | H  | L  | L  | H | L  | x |
| OR | H  | H  | H  | L  | H | L  | x |
| NOR | L  | L  | L  | H  | H | L  | x |
| XOR | L  | H  | H  | L  | H | L  | x |
| XNOR  | H  | L  | L  | H  | H | L  | x |
| FALSE | L  | L  | H  | H  | H | L  | x |
| TRUE  | H  | H  | L  | L  | H | L  | x |
| ADD | H  | L  | L  | H  | L | H  | Inv |
| SUB | L  | H  | H  | L  | L | L  | No  |
| SHL | H  | H  | L  | L  | L | H  | Inv |
| INC | L  | L  | L  | L  | L | L  | Inv |
| DEC | H  | H  | H  | H  | L | H  | No  |
| ADC | H  | L  | L  | L  | L | c' | Inv |
| SBB | L  | H  | H  | L  | L | c  | No  |

That is 16 operations.  In the operation selection, there is a Carry-In component (making 32 distinctions) and a Carry-Out component driving the arithmetic.

So, if my inputs are 5 bits (4 control lines plus the carry flag) the output should be able to be the 6 bits above.  I should be able to handle that with an EEPROM.  That will actually work quite nicely.

I actually think I will need a control signal to invert the carry flag on output as well.  I have room for that so I will have no problem adding it.  So, that is 6 output bits.

So, this is all with a simple 4-bit ALU.  Next I will need to hook up a second one and attempt to perform the same functions with 2 ALUs.

---

### 2022-Feb-12

Once I started to hook up multiple ALUs, I ended up seeing the carry output behave properly.  So I may not need to invert that output.  I want to wire up the whole ALU to check again.

ALU Testing

Now, the ALU is not dependent on the clock.  The ALU only has the output standard control line.  The other control lines will be the 4 control lines to select the ALU operation.

I do have 2 registers (both will be re-branded to be temporary registers) that are prepared for adding into the ALU.  I will only need to save room for the flags register.  I anticipate 2 boards for that.  But this is about the ALU.

The ALU is going to require 3 boards.  One for the upper ALU, one for the lower ALU, and one for the control logic.  I will need an inverter to handle the carry bit inversion and an AND gate to merge the `A=B` lines.  I think I can move the `A=B` merge onto the flags module.  So, that will leave an inverter and just the EEPROM for the control logic.

Ahh...!  But I also need to place a 74LS245 to control the output to the bus.  This also needs a control line.  This now makes things crowded and 3 board will be a requirement.

OK, here is the ALU "dry" layout.

"Dry" Layout

Notice the empty space in the center board to the right-hand side?  That is for the EEPROM which I need to order.  I will order that on Monday (since they do not ship over the weekend) and should have that by Wednesday.

---

First up is the foundational wire-up.  To that, I will add 4 control lines to the center board for the function selection.

---

That completed, I now need to start wiring up the control lines.  The 2 output lines need to be inverted.

---

I was able to get the Lower Temp 2 Register (stand by for the story on that one) hooked up.  It is not right.  I'm going to have to do some tracing to see where things went wrong.  But, I really don't think I have that in me tonight.  It was in the 90s here today and I did some work outside.  I am beat and can't really think clearly.

---

### 2022-Feb-13

I actually figured out what I did wrong last night (away from the breadboards).  I hooked up the wires to the wrong pins (well, duh!).  I neglected to confirm which pins wer A pins and which were B pins, so I simply put them all in line.  Actually, they alternate A and B pins, so I have them crossed.  This should be trivial to confirm.

The Instructions

In the picture, you cal clearly see that pins 21 & 22 are both hooked up (pin 23 is also hooked up but under the other wires in this photo), and should not be since I was only wiring up the B pins.

Which Were Not Followed

A quick adjustment and the "B calculation" result is passed along to the ALU output.

ALU Result is the "B" Input

---

Well, I just realized that I am going to run out of green hook-up wire before I get the ALU wired up.  This is going to suck as I will need green wire for any module I want to work on if I am going to stick with my wire-theming.

---

After getting the Temp 1 Lower wired-up with temp jumpers, I was able to confirm that that table appears to be correct at least for 8-bits.

---

I think I am going to move the 74LS04 and 74LS08 chips over to make room for a second EEPROM IC -- just in case I want to add some additional actions (most likely which flags will be updated by any given operation).

---

### 2022-Feb-14

OK, I got my supplies order out today.  I hope to have it by Wednesday.

In the meantime, I am working on how to determine equality.  The 74LS181 is supposed to have an `A=B` pin, but I am not able to determine what that is all about.  Even the schematic does not make sense.

So, my thought is to check the ALU output (all 16-bits) to see if they are all 0.  This will allow me to create opcodes like CMP which will do the subtraction but not update any registers and TEST which will do an AND but not update any registers.

To do this check a NOR gate will work well to compare pairs of bits.  I will need 8 gates to compare 16 bits, which is on 2 74LS02 chips.  Then all 8 outputs will need to be ANDed together (another 7 AND gates or 2 74LS08 chips) to get the final Zero Flag output.

On top of this, I need to control the inversion of the Carry Flag which will be controlled in the ALU Control Code.  And I have not even started to figure out < or > logic and store those bits.  However, the ALU is slowly getting bit enough to warrant considering moving that to a third column of boards in the overall layout and to "bridge" the bus between them.

So, taking into account what I might have built already, what could this look like?

| Left Column | Center Column | Right Column |
|:---:|:---:|:---:|
| Clock Module | Upper Program Counter | Upper Temp 1 Register |
| Upper MAR | Lower Program Counter | Lower Temp 1 Register |
| Lower MAR | Upper Flags | Upper ALU |
| Upper RAM | Lower Flags | Lower ALU |
| Lower RAM | Upper Stack | Upper Temp 2 Register |
| Upper A Register| Lower Stack | Lower Temp 2 Register |
| Lower A Register | Bus Bridge | ALU Control 1 |
| Upper B Register | Bus Contents | ALU Control 2 |
| Lower B Register | CPU Constants | Control Logic 1|
| Upper X Register | Upper Output | Control Logic 2|
| Lower X Register | Center Output | Control Logic 3|
| Reset Logic | Lower Output | Control Logic 4 |

A couple of things I like about this layout better:
1. The flags register is actually closer to the ALU, which will be driving the flag updates.
2. The computer feels more square meaning I should not have to stretch too far to wire things up (or stand to do it for that matter).
3. This layout will work better with the size of the board I am building on (really just a side benefit).
4. Overall, this will modularize the ALU and is being treated more like a micro-controller than anything.
5. The bus bridge is about the same width as width as a breadboard without the rails, so it will be easy to integrate.

This, then brings me back to the ALU Control Logic.  I need room for:
* 1 74LS04 Inverter
* 2 74LS30 Quad 2-Input NOR Gates
* 3 74LS08 Quad 2-Input AND Gates
* 2 28C16 EEPROMs

This is 8 ICs on 2 boards.  It will be tight, but still doable.

Now to tackle this whole Carry Flag inversion mess:

| Carry In | Invert | Carry Out |
|:---:|:---:|:---:|
| 0 | 0 | 0 |
| 0 | 1 | 1 |
| 1 | 0 | 1 |
| 1 | 1 | 0 |

Well, that looks like a simple XOR gate and I should be able to replace one of the Quad AND Gates with an XOR Gate and handle that a little better.

So, I am down to 7 AND gates, 1 XOR gate, and 8 NOR gates.  I also need 2 Inverters.

Now, the next step is to plan how to separate the ALU from what has already been built.  More to the point, how to separate Temp Register 1 and the ALU from the rest of what has been built.  That sounds easier than it really will be.  I will also need to collapse the ALU and separate out the ALU Control Logic.

I'm almost starting over, but not quite.

---

Well, I feel like I just took apart and reassembled Frankenstein's monster.  Lots of little things needed to be removed, relocated and reconnected.

That said, I have a fully assembled ALU module (well, the breadboard are all physically connected).  The next problem is that it will not fit on the board anymore.  I will have to find something bigger.

I know Home Depot has 1" rigid foam insulation; I just need to make sure it will be the correct size.

OK, so now what?  I do not have everything I need to wire-up the ALU.  I do know I want to re-route many of my current connections.

---

### 2022-Feb-16

Late last night and so far this evening, I have been working on wiring up the ALU outputs to the LED lights and the 74LS245 Buffer.  I managed to get all the control lines routed together.  I also have the output common control lines routed to the ALU Control Board and then back up to the 74LS245 to enable the output.

I am basically killing time until I get my supplies order -- on Saturday!  Grrrr....

Now, on the other hand, I could probably start the firmware component which will drive the ALU Control Logic.  This is going to be written in and maintained in the Arduino IDE, but will be a directory in this project.

This Arduino sketch will take advantage of the code I wrote to program other EEPROMS.  Let me get that established.

---

### 2022-Feb-17

Well, I was able to complete writing the EEPROM programmer and I actually received the EEPROMs today (not Saturday), so I have something I can work with.

That said, I have not yet tested the EEPROM.  I did use all 8-bits of the EEPROM output, so I have nothing left to latch the flags.  However, I think that will be easy to handle by latching all flags on any ALU operations (they all should be updated).  There is no enable on the ALU (it always does something).  So, the Flags Latch control line will have to be the thing that enables the flags update.

All-in-all, I think it was a good day as I have the supplies I need to complete the ALU module, the software written for the ALU Control, and the weekend coming up to be able to debug the while shebang.

In the meantime, I have a few wires to run....  Tomorrow.

---

### 2022-Feb-18

Today I was able to test the EEPROM flags that were being set.  I was able to find and resolve a couple bugs before I ever got the registers hooked up.

I also decided to add some LEDs to see what control bits the ALU Controller is sending to the ALUs themselves.

ALU Control Bits

And then I was able to get them labeled.

The alignment is not dead perfect, but I am not going to let that bother me.  From left to right:
* Invert Carry Flag before Latching
* S3 Control Line
* S2 Control Line
* S1 Control Line
* S0 Control Line
* M Control Line
* Carry Flag Input

---

Well, I just realized the Lower Temp Register 1 is wired backwards, such that the most significant bit from the bus is wired to the least significant in the register.

I thought I could work around this problem but it is totally backward.  I am going to have to correct it before I do anything more with the ALU.

---

OK, I did find a problem with the DEC functionality.  It was corrected and I think I have it working noe for 1 bit.

I had several problems with the ALU wired wrong.  All of those have been corrected as well.

So, now I am left with a mess of wires to replace with wires that are cut to length.

ALU Dry-Wire

Trust me: the picture does not do it justice.

---

### 2022-Feb-19

Well, I wired up half the Lower ALU today and then realized I have it all backwards again.  I may have even had the Lower Temporary Register 1 correct yesterday before I changed it.

My problem appears to be the inability to distinguish between the most significant bit and the least significant bit properly.

I'm starting to get annoyed about the whole situation.

---

I need to stop second-guessing myself.  I pulled it all apart to realize that it was correct.

---

I am seeing the Carry Flag is not working properly, but I am only testing with 8 bits so far.  The bits that I am loading for testing are:

* T1: 1010 1100
* T2: 1100 1010

This pattern should provide all 4 conditions that need to be considered in a predictable pattern, and then reversed.

So, with that said the following should be my 8-bit test results (which I need to ignore the carry bit for now):

| ## | Operation | T1 | T2 |  Results  |
|:--:|:---|:--:|:--:|:---:|
|  0 | NOT | Y  | | 0101 0011 |
|  1 | AND | Y  | Y  | 1000 1000 |
|  2 | NAND | Y  | Y  | 0111 0111 |
|  3 | OR | Y  | Y  | 1110 1110 |
|  4 | NOR | Y  | Y  | 0001 0001 |
|  5 | XOR | Y  | Y  | 0110 0110 |
|  6 | XNOR | Y  | Y  | 1001 1001 |
|  7 | FALSE | | | 0000 0000 |
|  8 | TRUE | | | 1111 1111 |
|  9 | ADD | Y  | Y  | 0111 0110 |
| 10 | SUB | Y  | Y  | 1110 0010 |
| 11 | SHL | Y  | | 0101 1000 |
| 12 | INC | Y  | | 1010 1101 |
| 13 | DEC | Y  | | 1010 1011 |
| 14 | ADC (0) | Y  | Y  | 0111 0110 |
| 14 | ADC (1) | Y  | Y  | 0111 0111 |
| 15 | SBB (0) | Y  | Y  | 1110 0010 |
| 15 | SBB (1) | Y  | Y  | 1110 0001 |

I did manage to find and correct a problem with the ADC logic in the EEPROM.

---

After correcting a problem with the Upper Temporary Register 1, I have everything wired up and I am ready to test again.  So once again, I need to set up my test scenarios -- this time for 16-bits.

* T1: 1010 1100 0011 0101
* T2: 1100 1010 0101 0011

| ## | Operation | T1 | T2 | C | Expected Results  |
|:--:|:---|:--:|:--:|:-:|:---:|
|  0 | NOT | Y  | | N | 0101 0011 1100 1010 |
|  1 | AND | Y  | Y  | N | 1000 1000 0001 0001 |
|  2 | NAND | Y  | Y  | N | 0111 0111 1110 1110 |
|  3 | OR | Y  | Y  | N | 1110 1110 0111 0111 |
|  4 | NOR | Y  | Y  | N | 0001 0001 1000 1000 |
|  5 | XOR | Y  | Y  | N | 0110 0110 0110 0110 |
|  6 | XNOR | Y  | Y  | N | 1001 1001 1001 1001 |
|  7 | FALSE | | | N | 0000 0000 0000 0000 |
|  8 | TRUE | | | N | 1111 1111 1111 1111 |
|  9 | ADD | Y  | Y  | Y | 0111 0110 1000 1000 |
| 10 | SUB | Y  | Y  | Y | 1110 0001 1110 0010 |
| 11 | SHL | Y  | | Y | 0101 1000 0110 1010 |
| 12 | INC | Y  | | N | 1010 1100 0011 0110 |
| 13 | DEC | Y  | | N | 1010 1100 0011 0100 |
| 14 | ADC (0) | Y  | Y  | Y | 0111 0110 1000 1000 |
| 14 | ADC (1) | Y  | Y  | Y | 0111 0110 1000 1001 |
| 15 | SBB (0) | Y  | Y  | Y | 1110 0001 1110 0010 |
| 15 | SBB (1) | Y  | Y  | Y | 1110 0001 1110 0001 |

OK, so I have carry problems to sort out already for the following logic operations:
* NOT
* NAND
* NOR
* XOR

A quick code change for the ALU Controller EEPROM and the actual ALU is complete.  The only thing left are the gates to handle the flags analysis prior to handing them off to the flags register.

ALU Nearly Complete

So, there are a few orange and yellow jumpers on the right side, which are used for loading the Temporary Registers.  There are 2 single (blue and green) jumpers in the center of the left of the module which were used for testing to disable the output from the ALU.  Finally, all the remaining multi-colored jumpers along the left are for connecting to the bus, and will be cleaned up once I have a bus to connect to.

Finally, along the bottom are the logic gates I will need to complete the analysis for the flags.  I just need to decide which flags I will be doing.

In the meantime, it is time to commit this work.

---

### 2022-Feb-20

This morning, I will start by consolidating the `Z` and the `P` flags for the flags register.  For this, I have 8 ICs on the module, 1 of which I know to be a 74LS04 Hex Inverter and another I know to be a Quad-XOR gate (I do not recall the IC number off the top of my head this morning).

So the layout looks something like this:

<table>
    <tr>
        <td>74LS02 - Quad NOR Gate</td>
        <td>74LS02 - Quad NOR Gate</td>
        <td>74LS86 - Quad XOR Gate</td>
        <td>74LS86 - Quad XOR Gate</td>
    </tr>
    <tr>
        <td>74LS04 - Hex Inverter</td>
        <td>74LS08 - Quad AND Gate</td>
        <td>74LS08 - Quad AND Gate</td>
        <td>74LS86 - Quad XOR Gate</td>
    </tr>
</table>

Most of this is for the Parity (`P`) and the Zero (`Z`) flags.  The Carry (`C`) flag also uses this logic but is already evaluated and ready to route off-module.

For the `Z` flag, each ALU result bit will be NOR'd with its neighbor, such that the result is high when both inputs are low (or `0`).  I have 16 ALU bits, so I need 8 NOR gates to perform these comparisons.  Then those 8 results all need to be AND'd together to get a single result -- which is the `Z` flag.

For the `P` flag, each of the same ALU result bits will be XOR'd with its neighbor such that the result is high when there is an *odd* parity between them.  Each of those 8 outputs will be XOR'd together into 4 outputs, each of which will be high if there is still *odd* parity between them.

Think about it: given input `0101`, the results will be `11` at the first set of gates and then `0` at the second (the original input was even parity already).  Also given input `1101`, the results are `01` and then `1` (the original input was odd parity and the `P` flag needs to be set to make the result even parity).

So, those 4 outputs from the prior level need to be XOR'd together to 2 results, then those 2 XOR'd together for the single `P` flag.

That means I need:
* 8 NOR gates (2 ICs)
* 7 AND gates (2 ICs)
* 15 XOR gates (4 ICs)

I do not have all the room I need; I am missing a 74LS86 Quad-XOR Gate to make this work.

I can move things over and make room, but the connections are going to be quite dense.

Let me go think in the other flags a bit.

So, it makes sense to add another row of boards.  Let me get that done.

So, with the additional board, the layout looks something like this:

<table>
    <tr>
        <td>74LS02 - Quad NOR Gate</td>
        <td>74LS02 - Quad NOR Gate</td>
        <td>74LS86 - Quad XOR Gate</td>
    </tr>
    <tr>
        <td>74LS04 - Hex Inverter</td>
        <td>74LS08 - Quad AND Gate</td>
        <td>74LS08 - Quad AND Gate</td>
    </tr>
    <tr>
        <td>74LS86 - Quad XOR Gate</td>
        <td>74LS86 - Quad XOR Gate</td>
        <td>74LS86 - Quad XOR Gate</td>
    </tr>
</table>

What the hell am I doing??!!

I can take care of all this with a second & third EEPROM and AND the results together.  Maybe one larger EEPROM if I look a little bit.

I think I can get away with 2 of the 28C16 EEPROM -- 1 for each byte and then AND the 2 results together.  Well, hang on.  I would be able to AND the 2 `Z` results together and then XOR the 2 `P` results together.  I already have an XOR gate, so there is no concern there.  I would just need to move an AND gate up to to the top ALU Control to make room for the 2 EEPROM.

Now, can I incorporate the logic for the `V` Flag?  I could but it will be an additional EEPROM.  So, I am going to actually leave the layout the way it is and just have an empty board.

---

After walking away for a bit, I reconsidered the `V` Flag.  It would only take an additional 2 address lines for the `A15` and `B15` inputs.  I already have `ALU15`.  So, with 2 28C16 EEPROMs, I would need:
* Address lines 0-7 for 8 bits of ALU results
* Address line 8 for selecting lower/upper ALU byte
* Address lines 9-10 for A7 and B7 inputs (tied low for the lower byte)

For the lower byte, the `V` output would be low and would be ignored.

With that, I think I have what I need to get started writing the firmware for this now.

---

That was actually an easy sketch to write.  I am ready to program both EEPROMs when I get them wired up.

Here are the ALU Control Logic boards at the moment:

ALU Control Logic Breadboards

The first thing I need to do is wire up the AND gates for the `Z` Flag.

Before I do that, I think I want to change what pins I use for the flag output.  I originally set those to be 0-2, but those are on the bottom of the EEPROM and the wire-up is not convenient.  If I move them to be 5-7, it will work out better.

---

OK, I am all wired up.  I also have programmed and surface tested the EEPROM.

I have 2 sets of bus rails which are prepared and ready for wire-up as well.  Once that is complete, it should largely complete the ALU.

---

Here is the completed ALU.  The only things left are to hook it up to the control logic and to hook it up to the flags register.

Completed ALU

I will commit my work again today at this point.  I have a number of schematics to draw and I am planning on changing the schematics to generally 1 per board.

You know, I really need to call out that this is not only the ALU but 2 16-bit Temporary Registers as well.  These 2 registers are used as inputs to the ALU and can be used for other things in the CPU (such as constructing an address when an address is being used as a base-reference point to build the address).

So, top to bottom to the right of the bus:
1. Upper Temporary Register 1
2. Lower Temporary Register 1
3. Upper ALU
4. Lower ALU
5. Upper Temporary Register 2
6. Lower Temporary Register 2
7. ALU Control firmware
8. ALU Flags firmware
9. Empty

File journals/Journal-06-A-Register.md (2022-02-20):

# Breadboard Computer v2

This project is related to building hardware more than a software project.  There will be some code added to this project later on for programming the firmware and downloading a program, but that will be in the final stages.

This project is inspired by [Ben Eater's Breadboard Computer](https://eater.net/8bit).  Currently as this get started, I have his computer nearly complete and I am working on the final connections and debugging before I get into the control logic.

As usual with my personal projects, I am compelled to keep a journal of this progress.  As usual with my journals, I will not go back and edit anything historical as these are my continuing thoughts rather than documentation of the final product.

## A Register

The A Register is an exact duplicate of the [Temporary Register](Journal-04-Temporary-Register.md).  As such, there will not be as many pictured and commentary on the process.  I will comment on the overall progress.

### 2022-Feb-06

So, while I am waiting for my [MAA components](Journal-05-Memory-Address-Module.md#2022-feb-04) to get settled, I have already completed the foundational wire-up.

---

### 2022-Feb-07

I worked a bit on the A Register.  My vendor was willing to re-send the mis-picked ICs without charge.  I should have my replacements in about 2 days.

In other news, I believe I will be able to put a screen onto this computer which should be able to output character data.  This 'monitor' should be able to be driven by an Arduino Nano as a micro-controller.

---

### 2022-Feb-08

Well, today I realized I used the wrong color wires for some of my intra-board connections.  They should have been green for the on-board hook-ups; I used blue.  I want to go back and resolve that: it's my inner OCD!

In the meantime, I did complete the A Register wire-up.  It is not tested yet.  I will do that tomorrow as I am defeated with the above realization.

---

### 2022-Feb-09

Today I started working on the Microcode for each instruction.  I have some time to kill before my supplies arrive.  Working on this has exposed some problems -- namely that I really need 2 temp registers to work with the ALU.  Well, damn!

---

OK, I was able to get the boards re-wired with the correct colors.  It's a detail, I know.

At the same time, I have about a third of the microcode designed.  I think the longest instruction will require 18 clock cycles -- for hardware and software interrupts each.

I do expect to get the replacement ICs Saturday, which is later than I want.  On the other hand, I did get the RAM today, so that is a benefit.

I also realized I need 2 temp registers to operate the ALU -- 1 temp register plus the A register would not deliver what I need.  So, I need to reconsider the layout again.

Overall, the last 2 days might seem like defeat after defeat, but in reality it is all progress.

Now, I think I have all the parts I need to electrically connect up the bench-top power supply.  This will allow me to have more stable power (compared to the noisy switching adaptor I have been using).

I also realized today I need to have several constant values to be used for the CPU.  I will need to be able to set those up and deliver those to the bus on demand as pseudo-registers.  At the moment, I am looking at something close to 64-80 control bits.  I need to figure out how to reduce that ahead of the control logic build.

That said, the A Register is actually complete.

Completed A Register

Tomorrow, I complete the schematic, a copy of the Temp Register, of which I now need 2.

---

### 2022-Feb-11

Well, I had a but of an epiphany yesterday while I am out and about: Why am I worried about stupid optimizations when I need to be worried about getting this iteration completed.  As such, why do I need a MAR, MIR, MAA, and MAP when all I really need is a MAR and an ALU.  The same question goes for the stack: why do I need it when I can use the ALU?  Yeah, it may take an extra clock cycle or two, but I am going for the blinking lights more than I am going for speed.  If I want speed, I will buy another laptop.

So, I need to go back and revisit my work on the Memory Address Module (which will be torn down and redone), and the A and Temporary Registers (as they may be relocated and need to be flipped.

With that said, I am going paste this same update into all 3 Journals since they will all need to be revisited.

---

### 2022-Feb-18

What used to be the A Register Module has now become the Temporary Register 1 Module.  And the Lower Temporary Register 1 portion is wired totally wrong.

I need to correct this and I will need to re-make an A Register.  Until I get to a new A Register, I am going to continue the monologue on this module under the Temporary Register 1 Journal.

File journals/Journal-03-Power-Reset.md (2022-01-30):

# Breadboard Computer v2

This project is related to building hardware more than a software project.  There will be some code added to this project later on for programming the firmware and downloading a program, but that will be in the final stages.

This project is inspired by [Ben Eater's Breadboard Computer](https://eater.net/8bit).  Currently as this get started, I have his computer nearly complete and I am working on the final connections and debugging before I get into the control logic.

As usual with my personal projects, I am compelled to keep a journal of this progress.  As usual with my journals, I will not go back and edit anything historical as these are my continuing thoughts rather than documentation of the final product.

## Power Reset Module

Next, I am going to work on the Power Reset Module.  This module is used to put the CPU into a known state prior to executing code.  This will include loading the first instruction location from some ROM location (if I follow the MOS 6502, that will be something like `0xfffe` & `0xffff`).  If I follow the x86 convention, I can set the Program Counter to be `0xffff` and load the first instruction from there.  Since jumps will require an offset, this may need to be `0xfff0`.

At the same time, I have a need to have a Zero Register in the system.  This should be able to be included on this module as I anticipate there will be room.

---

### 2022-Jan-29

So, the power on-reset logic only requires a 74LS14 (Inverter with Schmitt trigger).  Integrating that into the control logic is going to require a 74LS32 (OR gate).  That leaves room for at most 3 additional components on the one board:
* 74LS157 (Quad 2-to-1 data selector (for zero or reset starting address))
* 74LS245 (3-state Buffer)

The problem here is that the clock is not firing during this time, so I need all kinds of special logic to perform this reset and start executing at the defined address.

What I did consider was a special instruction (`0x00`) which will perform the reset and start executing.  The problem with thats instruction is that if we start executing unprogrammed memory, we have a change of restarting.  That could be a feature!

So, if that is the case, I have no need to the 2 X 74LS157 chips as there would only ever be the need for a Zero-Register.  It would also give me the chance to add a couple of stand-alone LEDs for the reset indicator and for the Zero-Register output indicator (no need for register contents and no need for input from the bus).

With that, here is the basic board layout:

Power Reset & Zero Register Module Basic Layout

The LED on the left will indicate the power-up reset in action while the LED on the right will indicate the Zero-Register is being output to the bus.

Since the 2 ICs on the left are not going to be fully populated and this board will be on the bottom-left corner, I may move the RC combo to the upper side of the board.  Only 1 inverter will be used and 2 OR gates will be used -- no matter what the bottom side of those ICs can be left unpopulated.

Of course, as soon as I have it wired up, there is something not working.  Time for the scope.

---

So, my overly simplistic power up circuit was, well....  overly simplistic.  As a result, I ended up with a ton of jitter, which would make a mess of things for sure.  Have a look at one of the worst cases I saw:

Bad jitter

Since I was working with a Schmitt trigger IC, and because it is supposed to eliminate noise like what I was experiencing, I decided to try to wire 3 of them up in series.  This should (in my mind anyway) reduce the jitter for each circuit.  It did:

Much better

I really like the nice, sharp drop now.  Plus, the voltage is much better.  I also ended up adding a 1µF capacitor across the power rails and a 0.01µF capacitor at the 74LS14 IC across the power pin and ground.  However, that have the effect of having a 2 capacitors connected in parallel.  For a moment I thought the formula would have that a much smaller capacitance, but I had the formulas backward.  Capacitance in parallel and resistance in series are additive.

That said, I am going to remove the 0.1µF capacitor and move the 1µF capacitor to the power pin for the 74LS14.  I really need to test that change.  And that is working the way I need it to.

---

OK, I think I actually have this (split is it?) module complete.  I ran into an issue where I may have a bad OR gate, giving output to one of the input pins.  I need to test that IC a little more, but in the meantime, I have replaced it.

The final design has 4 of the 6 Inverters being used on the 74LS14.  I needed one additional one for outputting the Zero Register onto the bus since the signal is active low.

The final board looks like this:

Completed Power-Up/Zero Register Module

There are 2 temporary lines that are pulled low.  One is for halting the clock and the other is for clearing all the registers.

The only thing left is to create a schematic.

Power Reset Module Schematic

---

### 2022-Jan-30

I realized while I was documenting this module for the [Readme](../Readme.md), I neglected to add a manual reset to the module.  I will need to add that today.

Here is the updated schematic with the reset button added.

Updated Power Reset Module Schematic

This has been tested and works properly.

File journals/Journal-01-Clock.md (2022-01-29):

# Breadboard Computer v2

This project is related to building hardware more than a software project.  There will be some code added to this project later on for programming the firmware and downloading a program, but that will be in the final stages.

This project is inspired by [Ben Eater's Breadboard Computer](https://eater.net/8bit).  Currently as this get started, I have his computer nearly complete and I am working on the final connections and debugging before I get into the control logic.

As usual with my personal projects, I am compelled to keep a journal of this progress.  As usual with my journals, I will not go back and edit anything historical as these are my continuing thoughts rather than documentation of the final product.

## Clock Module

The first module to build is the Clock Module.  It will be required for nearly every other module that will be built.

---

### 2022-Jan-21

I got started with a second Clock Module today.  I started with the bi-stable timer.  It was not working (or so I thought) until I realized I ordered 10K Ohm variable resistors instead of 1M Ohm ones.

---

### 2022-Jan-22

OK, so I admit I am starting this Journal today.  I back-dated yesterday's entry since that was what I worked on yesterday and overnight I decided to create this Journal.

Today, after getting the Journal started, I worked on a board for testing.  Part of this was done yesterday and I completed it today.  Here is a picture of the near-complete board:

Test Board

This test board was built on a BB830 breadboard.  However, today I ordered several BB400 breadboards and will migrate this to the new smaller board when they arrive.

---

For the Clock Module (Clock or Timer?  They are "timer" Integrated Circuits, but the intended output is a regular clock signal, so I am going to refer to it as a Clock Module), I ordered the replacement potentiometer (or variable resistor) today.  Well, a number of them.  I can pull the original one if I need to test something, but I will likely be working and documenting as much as I can before they arrive.

I also have plenty still to do for the original computer.

---

Before I go there, the Clock Module has a 74LS32 OR-gate used.  Only 1 OR gate.

I think I recall from my Boolean Algebra that I can replace OR logic with inverted inputs with AND logic.  Something like this:

`A | B = (A' & B')'`

So, let's set up a truth table to see if I am lying.

| A | B | A' | B' | A' & B' | (A' & B')' |
|:-:|:-:|:--:|:--:|:---:|:---:|
| 0 | 0 | 1  | 1  | 1 | 0 |
| 0 | 1 | 1  | 0  | 0 | 1 |
| 1 | 0 | 0  | 1  | 0 | 1 |
| 1 | 1 | 0  | 0  | 0 | 1 |

So, I can replace the single OR gate with 3 additional NOT (inverters) and 1 additional AND gate.

The 74LS08 is a Quad-AND gate IC.  I am using 3 of the 4 currently, so there is 1 available.  I need 1 and this will use the entire capacity of this chip.  Nice and efficient.

The 74LS04 is a Hex-Inverter IC.  I will be using 2.

***Note:*** *Ben Eater's Clock Module also outputs the inverse of the clock signal which is used only by the Control Module.  My plan is to invert this signal on the Control Module since it will better be represented by the Common Interface I am planning to put forward.  This plan saves me an inverter and a long signal line around the boards.*

This will leave 4 available inverters.  I need 3 inverters for this changed logic, leaving 1 unused gate.

Overall this change saves me 1 IC chip.  This feels like an appropriate improvement, since the power will be a concern with the number of chips in this computer.

---

I wired up the monostable (de-bounced) circuit on the new Clock Module.  They are not yet connected so the circuits work independently.  Here is the progress so far:

2 timer circuits

The LED lights are there to indicate the clock pulse for each circuit and will remain on the final board.

---

I now have all 3 timer circuits built.  They are not connected yet.  This (generally speaking) is all the analog circuitry that will be built into the computer (with the exception of the output display).

3 555 Timer Circuits

The 3 LED lights are (from left to right):
* The astable timer (flickering quite fast since I still have the incorrect variable resistor).
* The monostable timer, activated by the push button to the left.
* A green LED to indicate that the timer is in run mode.

The next step will be to hook up the logic circuits to output the correct clock signal and halt the clock with the proper control signal.

Connecting the logic was quick for a temporary wire-up.  The Clock Module tests out properly.  The sliding switch properly selects between the astable and monostable timer circuits, with the green LED on when the Clock Module is in run mode.

Temporary Wire-Up

Assert the Control Line

This is a very successful test and the only thing left at this point is to replace all the temporary wires with proper cut-to-length wires and clean up the LED and resistor lengths.

---

Now that it is all cleaned up, here is the board:

Cleaned up Clock Module

I am able to halt the clock.  Notice the interface point has been extended to the proper location on the board (the yellow wire).

Cleaned up Clock Module

Also, with the Clock Module in single-pulse mode (the sliding switch now to the left), I am able to manually trigger a clock pulse.

Cleaned up Clock Module

---

This actually completes the updated Clock Module.  These updates accomplish the following:
1. Remove an IC and better utilize the remaining ICs.
2. Create Common Interface Points on the module, which will match every other module built.
3. Added some additional indicator lights for the module state, including halted by the Control Logic.

I also added a current-limiting resistor to the blue LED which is driven from the 74LS08.  Ben Eater does not use them in the videos.  I will.  I have burnt a few LEDs and ICs.

That said, the LED specs state that the current forward is 20mA and the voltage forward is 3.5V.

LED Specifications

The data sheet for the 74LS08 states the max output current (I<sub>OH</sub>) is 0.4mA.

74LS08 Data Sheet

0.4mA is certainly less than the LED's limit of 20mA.

Now, this is not to say that I have read and interpreted all these data points properly.  In fact, I would bet I have not.  I never claimed to be a professional.  Or an expert.  I'll use the resistors, thank you very much.

---

### 2022-Jan-23

After the first commit, I decided to separate my journals into each module and place them into a separate folder.  As a result, I had several links to clean up.

---

I was able to find KiCAD, which is open source.  I downloaded version 6.0.1 and installed it on my system.

From there I was able to create a schematic of the Clock Module and export that to a .jpg as well.  Here is the result:

Clock Module Schematic

The base schematic is the same as the original.  I was specific about which LEDs I added and added instructions on how to set up the common interface points.

---

### 2022-Jan-24

I did find some errors in the schematic (things like connections not completed).  I cleaned those up today and re-published the above image.  That said, I also had to update my naming convention so I can keep them separate.

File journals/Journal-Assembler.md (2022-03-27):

# Breadboard Computer v2

This project is related to building hardware more than a software project.  There will be some code added to this project later on for programming the firmware and downloading a program, but that will be in the final stages.

This project is inspired by [Ben Eater's Breadboard Computer](https://eater.net/8bit).  Currently as this get started, I have his computer nearly complete and I am working on the final connections and debugging before I get into the control logic.

As usual with my personal projects, I am compelled to keep a journal of this progress.  As usual with my journals, I will not go back and edit anything historical as these are my continuing thoughts rather than documentation of the final product.

## Assembler

The breadboard computer will need to be able to handle programs that are significantly larger.  To hand-assemble them will not be a good thing.  So, I will need to write an assembler for the toolchain.

### 2022-Mar-19

So, as I am thinking about how to test the hardware, I feel I need to be able to handle much more granular iterative development and testing.  At the moment I have the Program Counter, Memory Address Register, Memory Module, 2 Temporary Registers, and the ALU built out -- all with relatively little testing.  So, I need to "drop back 10 and punt" a little bit.

This is why I decided to start an assembler for the toolchain.  There will be other components as well -- such as something to build a microcode binary and programs for the computer for exercising the system.

But I also may want to extract this assembler from this project and use it in the next computer build, so I want to make it flexible as well.

I start with the basic output messaging.

---

### 2022-Mar-20

OK, so do I want to figure out how to hand-scan the assembler (not really) or do I want to use `flex` to tokenize the input?

I'm thinking I do want to do this since it will make scanning and tokenizing the input far simpler.  Then, I should be able to hand-code the parser.  However, this also eliminates the goal to make the assembler configurable.

---

### 2022-Mar-21

OK, so let's go with `flex`.  The first thing I want to do is to be able to include other files.  So, the first thing will be to implement the `.include` directive.

---

That is working well enough.  I have comments supported as well.

Next, to implement some search paths in the source files as well, so I do not need to type the full path in the source.  Later, I will add command line parameters to set this table as well.

---

OK, I have that working now.  I can specify the paths in the source from which to add additional search paths.  This is cool.

Now, I have cleaned up some of the error conditions and improved the messaging.  Now, on to defining the architecture using an `.architecture` directive.  Should I make it just an `.arch` directive?  I think so.

A strong point to make here is that only some directives will be available from within the `.arch` include file.

I think I am going to have to make the EOL be a part of the semantic analysis, meaning I need to return it as a token.

---

### 2022-Mar-22

What do do next today?  I do have the `TOK_EOL` handled in the scanner thus far.  So, I think the next thing is going to be to start a top-down parser.  This will mean I need my own `main` function, not the one supplied by flex.

OK, what the hell is returning a `'0'`?

```
Unimplemented token is parser (software/assembler/parser.c:27): 0
```

Ahhh...  it's `<<EOF>>`.

OK, so let's try to get a register defined.

When I define a register, do I want to specify how many bytes wide it is?  If I consider James Sharman's computer (2 different register sizes), then yes I do.  Since I would not want that to be in hex, I need to discern between hex and decimal numbers.  I think I will implement the prefix `0x`, and for that matter, `0b` and `0` (octal).

But this also means I will need to convert the numbers to a proper foundational type (not string) and then return that value rather than the string value to the parser.

I can now parse the file, but I have no storage for registers.  I need to build that out.  But before I do that, I should handle several error conditions.  This means I really need to get some error reporting APIs in place.

OK, I have the registers being captured in a register table.  I am also capturing the number of bits wide each register is and I can report on them at the end.  All is working well.

So, the next thing will be to parse the memory for the architecture (and create a buffer in which to write the bytes).  After that will be a list of opcodes and how to interpret them.

All in all, since I am hand-coding the parser, I should be able to keep this generic enough that I can generally support any architecture.  Now, I may need to enhance the tool set to handle other arch requirements....  But the foundation will be there.

---

### 2022-Mar-23

I took care of the memory ranges.  Right now, each range remains distinct; I have made no effort to optimize/combine adjacent memory ranges into a single range.  Right now I am going for function, not speed.  I am a bad programmer in that performance should always be considered, but how much time am I going to invest to improve speed to save how much time on the back end?  And introduce how many obscure bugs?  The brute-force method is elegant enough in this case.

So, now for the really hard task: defining the opcodes.  Generalizing, opcodes come in 3 forms:
1. just an opcode (such as `nop`) with no parameters
2. an opcode with 1 or 2 register parameters (`psh a` or `mov b,a`)
3. an opcode with 1 or 2 parameters where the last parameter is a numeric value (`jmp 0x1234` or `add a,3`)

Now, the number can also be the name of a label, or a location in memory.  I could also provide directives for symbolic constants as well (`.equ` comes to mind).

OK, focus, Adam.  1 thing at a time: opcodes.  For now, I will only support numbers, not labels.

---

### 2022-Mar-26

I have been working on the assembler a little bit each day over the last few days.  However, I have come to the conclusion that I am doing it wrong.

I have been breaking up the opcode definition into parts in order to be able to store it like a compiler would.  However, that's really not what I am wanting to do.  I really need to be able to clean up the definition (remove extra spaces, change the case, etc.) so that I can match the string easily when actually assembling.

This, then, will mean that I will need to write a function to match a line from the assembly code to an op-code to define what the resulting binary code will be.

The first thing I need to do is to write a function to clean up a string to make it into a standard format.  A standard format will be:
* no leading or trailing spaces
* only 1 space between the mnemonic and its operands
* no spaces between the operands or its components
* only 1 replacement value per mnemonic will be allowed, identified by `$(8)` or `$(16)`, depending on size allowed

This also means I will be able to take a line to be assembled and convert the any constant number to be either `$(8)` or `$(16)` depending on the constant's size and search for the proper opcode to use.  I will be able to fall-back to searching for a larger constant size (an 8-bit will fit into a 16-bit constant) if not found.

---

This settles the architecture definition and how to load up assembler with what its capabilities are.  Now, for the actual assembler.  Since I am only going to be outputting a binary file (not ELF or anything fancy), this should be easy to deal with.

I need to be able to position in the output binary.  Typically, this is done using the `.org` directive.  I am going to make the rule that the position can only be the same place or forward.  Going backward in memory is not allowed.  So, I am going to need to maintain a position in memory and let the `.org` directive update it.

---

### 2022-Mar-27

I completed a ton of coding yesterday and today I actually have a reasonably functioning assembler.  It does not protect me from myself and there is a whole lot of error checking that is needed for this to be considered robust, but I can create a binary instruction set.

I just need to output the results to a file.

Done.

I am going to prepare to commit these changes.  The problem here is that the assembler is largely undocumented and still needs some work.  But this is a huge update!

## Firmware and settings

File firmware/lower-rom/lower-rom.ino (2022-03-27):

/*****************************************************************************************************************//**
* @file         rom
* @brief        EEPROM Programmer for the lower ROM chips 
* @author       Adam Clark
*
* This code will include the lower ROM binary array and add it into this source.  It will then write to the ROM 
* using the Arduino to accomplish the write.
* 
*///==================================================================================================================



/*****************************************************************************************************************//**
* The following section is the common code used to program the EEPROM.  This section will be repeated with each 
* separate piece of firmware (at least unless/until I can figure out how to tell the Arduino IDE to import something
* from another folder).
* 
* In the meantime, I expect to have to do multiple-maintenance on anything in this section.
*///==================================================================================================================



//
// -- Define some constants that will be used to interact with the Arduino
//    --------------------------------------------------------------------
#define PIN_DATA    2
#define PIN_CLOCK   3
#define READ_BYTE   4
#define CHIP_ENAB   5
#define WRITE_BYTE  6

#define DATA0       8
#define DATA7       15


#define ROM_BYTES   8192


//
// -- Set an address to be read from/written to
//    -----------------------------------------
void setAddress(int address) {
  address &= 0x1fff;       // safety first -- make sure the address is only 13 bits wide
  digitalWrite(WRITE_BYTE, HIGH);
  digitalWrite(READ_BYTE, HIGH);
  
  shiftOut(PIN_DATA, PIN_CLOCK, MSBFIRST, address >> 8);
  shiftOut(PIN_DATA, PIN_CLOCK, MSBFIRST, address & 0xff);

  delay(1000);
}


//
// -- Write a single byte of data to an address in the EEPROM
//    -------------------------------------------------------
void writeEeprom(int address, byte data) {
  setAddress(address);

  for (int pin = DATA7; pin >= DATA0; pin --) {
    pinMode(pin, OUTPUT);
  }

  digitalWrite(WRITE_BYTE, LOW);

  for (int pin = DATA7; pin >= DATA0; pin --) {
    digitalWrite(pin, data & 1);
    data = data >> 1;
  }

  delayMicroseconds(10);
  
  digitalWrite(WRITE_BYTE, HIGH);
  delay(50);
}



//
// -- Read a single byte from an address on the EEPROM
//    ------------------------------------------------
byte readEeprom(int address) {
  setAddress(address);
  
  for (int pin = DATA0; pin <= DATA7; pin ++) {
    pinMode(pin, INPUT);
  }

  byte data = 0;

  digitalWrite(READ_BYTE, LOW);
  delayMicroseconds(10);

  for (int pin = DATA0; pin <= DATA7; pin ++) {
    data = (data << 1) | digitalRead(pin);
  }

//  digitalWrite(READ_BYTE, HIGH);

  return data;
}


//
// -- Dump the contents of the entire EEPROM to the Serial Port
//    ---------------------------------------------------------
void dumpEeprom(void) {
  char buf [80];
  
  Serial.println();
  Serial.println("Dumping the contents of the Eeprom\n");
  Serial.println();
  Serial.println("       0x00 0x01 0x02 0x03 0x04 0x05 0x06 0x07   0x08 0x09 0x0a 0x0b 0x0c 0x0d 0x0e 0x0f");
  Serial.println("       ---- ---- ---- ---- ---- ---- ---- ----   ---- ---- ---- ---- ---- ---- ---- ----");

  for (int base = 0; base < ROM_BYTES; base += 16) {
    sprintf(buf, "0x%03x: ", base);
    Serial.print(buf);

    for (int offset = 0; offset < 16; offset ++) {
      int addr = base + offset;
      sprintf(buf, "0x%02x ", readEeprom(addr));
      Serial.print(buf);

      if (offset == 7) Serial.print("  ");
    }

    Serial.println();
  }
}


//
// -- Erase the EEPROM back to factory (burns one of the write cycles)
//    ----------------------------------------------------------------
void eraseEeprom(void) {
  Serial.print("Erasing EEPROM");
  
  for (int i = 0; i < ROM_BYTES; i ++) {
    writeEeprom(i, 0xff);
    
    if (i % 32 == 0) Serial.print(".");
  }

  Serial.println();
}



//
// -- Perform the EEPROM programmer initialization
//    --------------------------------------------
void performInitialization() {
  digitalWrite(PIN_CLOCK, LOW);
  digitalWrite(PIN_DATA, LOW);
  digitalWrite(WRITE_BYTE, HIGH);
  digitalWrite(READ_BYTE, HIGH);
  digitalWrite(CHIP_ENAB, HIGH);

  pinMode(PIN_DATA, OUTPUT);
  pinMode(PIN_CLOCK, OUTPUT);
  pinMode(READ_BYTE, OUTPUT);
  pinMode(WRITE_BYTE, OUTPUT);
  pinMode(CHIP_ENAB, OUTPUT);
}



/*****************************************************************************************************************//**
* The following section is directly the task to complete.  
* 
* In this case, we are going to program the ROM with its binary data.
*///==================================================================================================================


const uint8_t romData[] PROGMEM = {
    0x01, 0x02, 0x04, 0x08, 0x10, 0x20, 0x40, 0x80, 0x40,
    0x20, 0x10, 0x08, 0x04, 0x02, 0x01, 0x02, 0x04, 0x08,
    0x10, 0x20, 0x40, 0x80, 0x40, 0x20, 0x10, 0x08, 0x04, 
    0x02, 0x01, 0x02, 0x04, 0x08, 0x10, 0x20, 0x40, 0x80, 
    0x40, 0x20, 0x10, 0x08, 0x04, 0x02, 0x01, 0x02, 0x04, 
    0x08, 0x10, 0x20, 0x40, 0x80, 0x40, 0x20, 0x10, 0x08, 
    0x04, 0x02, 0x01, 0x02, 0x04, 0x08, 0x10, 0x20, 0x40, 
    0x80, 0x40, 0x20, 0x10, 0x08, 0x04, 0x02, 0x01, 0x02, 
    0x04, 0x08, 0x10, 0x20, 0x40, 0x80, 0x40, 0x20, 0x10, 
    0x08, 0x04, 0x02, 0x01, 0x02, 0x04, 0x08, 0x10, 0x20, 
    0x40, 0x80, 0x40, 0x20, 0x10, 0x08, 0x04, 0x02, 0x01, 
    0x02, 0x04, 0x08, 0x10, 0x20, 0x40, 0x80, 0x40,
    0x20, 0x10, 0x08, 0x04, 0x02, 0x01, 0x02, 0x04, 0x08,
    0x10, 0x20, 0x40, 0x80, 0x40, 0x20, 0x10, 0x08, 0x04, 
    0x02, 0x01, 0x02, 0x04, 0x08, 0x10, 0x20, 0x40, 0x80, 
    0x40, 0x20, 0x10, 0x08, 0x04, 0x02, 0x01, 0x02, 0x04, 
    0x08, 0x10, 0x20, 0x40, 0x80, 0x40, 0x20, 0x10, 0x08, 
    0x04, 0x02, 0x01, 0x02, 0x04, 0x08, 0x10, 0x20, 0x40, 
    0x80, 0x40, 0x20, 0x10, 0x08, 0x04, 0x02, 0x01, 0x02, 
    0x04, 0x08, 0x10, 0x20, 0x40, 0x80, 0x40, 0x20, 0x10, 
    0x08, 0x04, 0x02, 0x01, 0x02, 0x04, 0x08, 0x10, 0x20, 
    0x40, 0x80, 0x40, 0x20, 0x10, 0x08, 0x04, 0x02, 0x01, 
    0x02, 0x04, 0x08, 0x10, 0x20, 0x40, 0x80, 0x40,
    0x20, 0x10, 0x08, 0x04, 0x02, 0x01, 0x02, 0x04, 0x08,
    0x10, 0x20, 0x40, 0x80, 0x40, 0x20, 0x10, 0x08, 0x04, 
    0x02, 0x01, 0x02, 0x04, 0x08, 0x10, 0x20, 0x40, 0x80, 
    0x40, 0x20, 0x10, 0x08, 0x04, 0x02, 0x01, 0x02, 0x04, 
    0x08, 0x10, 0x20, 0x40, 0x80, 0x40, 0x20, 0x10, 0x08, 
    0x04, 0x02, 0x01, 0x02, 0x04, 0x08, 0x10, 0x20, 0x40, 
    0x80, 0x40, 0x20, 0x10, 0x08, 0x04, 0x02, 0x01, 0x02, 
    0x04, 0x08, 0x10, 0x20, 0x40, 0x80, 0x40, 0x20, 0x10, 
    0x08, 0x04, 0x02, 0x01, 0x02, 0x04, 0x08, 0x10, 0x20, 
    0x40, 0x80, 0x40, 0x20, 0x10, 0x08, 0x04, 0x02, 0x01, 
    0x02, 0x04, 0x08, 0x10, 0x20, 0x40, 0x80, 0x40,
    0x20, 0x10, 0x08, 0x04, 0x02, 0x01, 0x02, 0x04, 0x08,
    0x10, 0x20, 0x40, 0x80, 0x40, 0x20, 0x10, 0x08, 0x04, 
    0x02, 0x01, 0x02, 0x04, 0x08, 0x10, 0x20, 0x40, 0x80, 
    0x40, 0x20, 0x10, 0x08, 0x04, 0x02, 0x01, 0x02, 0x04, 
    0x08, 0x10, 0x20, 0x40, 0x80, 0x40, 0x20, 0x10, 0x08, 
    0x04, 0x02, 0x01, 0x02, 0x04, 0x08, 0x10, 0x20, 0x40, 
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
};



//
// -- Complete the EEPROM programming
//    -------------------------------
void programEeprom() {
    int addr;
  
    for (addr = 0; addr < sizeof(romData); addr ++) {
        if ((addr & 0xfff) == 0) {
            Serial.println();
            Serial.print(addr);
            Serial.print(": ");
        }
        if ((addr & 0xff) == 0) Serial.print(".");
        writeEeprom(addr, pgm_read_byte_near(romData + addr));
    }


    for ( ; addr < ROM_BYTES; addr ++) {
        if ((addr & 0xfff) == 0) {
            Serial.println();
            Serial.print(addr);
            Serial.print(": ");
        }
        if ((addr & 0xff) == 0) Serial.print(".");
        writeEeprom(addr, -1);
    }
}


//
// -- Perform a special write sequence for the SDP commands
//    -----------------------------------------------------
void sdpWrite(int address, byte data) {
  setAddress(address);

  for (int pin = DATA7; pin >= DATA0; pin --) {
    pinMode(pin, OUTPUT);
  }

  for (int pin = DATA7; pin >= DATA0; pin --) {
    digitalWrite(pin, data & 1);
    data = data >> 1;
  }

  digitalWrite(CHIP_ENAB, LOW);
  digitalWrite(WRITE_BYTE, LOW);
  delayMicroseconds(1);
  digitalWrite(WRITE_BYTE, HIGH);
  digitalWrite(CHIP_ENAB, HIGH);
  delayMicroseconds(1);
}





void disableSoftwareDataProtection(void) {
  Serial.println(".. Attempting to being the chip out of write-protect mode");

  digitalWrite(READ_BYTE, HIGH);
  digitalWrite(WRITE_BYTE, HIGH);
  digitalWrite(CHIP_ENAB, HIGH);

  delay(10);
  
  sdpWrite(0x1555, 0xaa);
  sdpWrite(0x0aaa, 0x55);
  sdpWrite(0x1555, 0x80);
  sdpWrite(0x1555, 0xaa);
  sdpWrite(0x0aaa, 0x55);
  sdpWrite(0x1555, 0x20);

  Serial.println(".. Done (good luck!)");
  digitalWrite(CHIP_ENAB, LOW);
}



//
// -- Standard Setup function
//    -----------------------
void setup() {
  performInitialization();

  Serial.begin(57600);
  Serial.println("Welcome to the ROM-BIOS/BASIC EEPROM Programmer");
  Serial.println("  This software will program the firmware for the ROM Memory");

  disableSoftwareDataProtection();

  writeEeprom(0x1234, 0b11010101);
  Serial.println();

  delay(2000);

  
  Serial.println(readEeprom(0x1234));
//  Serial.println(readEeprom(0));
//  Serial.println(readEeprom(0));
//  Serial.println(readEeprom(0));
//  Serial.println(readEeprom(0));
//  programEeprom();
//  dumpEeprom();
  Serial.println();
  Serial.println("All done!");
}


//
// -- Standard post-initialization loop function
//    ------------------------------------------
void loop() {
  // -- nothing to do here; what we want to do should not be in a loop
}

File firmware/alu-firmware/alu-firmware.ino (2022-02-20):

/*****************************************************************************************************************//**
* @file         alu-firmware
* @brief        EEPROM Programmer for the ALU firmware
* @author       Adam Clark
*
* This code is adapted from the videos provided by Ben Eater.  It is  not a direct line-for-line copy, but I cannot
* claim the algorithms as my own.  I watched the videos and understood the point and then "wrote" a version of what
* I just watched.
* 
* If this code is used anywhere please give Ben honorable mention.
* 
* -------------------------------------------------------------------------------------------------------------------
* 
* This code will program the EEPROM specifically for the ALU Control Logic.  So, what control logic would be needed 
* for an ALU?  Well, the there are 4 control signals, 1 mode signal, and 1 carry bit which all need to be controlled 
* whittled down to 16 ALU-related microcode instructions.  Each of the 16 instructions would have to set the 6 
* control lines properly for the instruction and determine if the incoming and outgoing carry bit need to be inverted 
* before and after the operation.
* 
* Overall, I will be able to handle all this with 4 lines from the Control Module rather than 6 lines and lots of 
* additional logic gates.  I think this is a win.
* 
* The 16 microcode operations will be:
* * NOT
* * AND
* * NAND
* * OR
* * NOR
* * XOR
* * XNOR
* * FALSE
* * TRUE
* * ADD
* * SUB
* * SHL (1-bit)
* * INC
* * DEC
* * ADC
* * SBB
* 
* Each will have its own set of the 4 control lines for the ALU with its mode line set (32 possibilities) and several
* will have a need to invert the carry bit, which will be included as an input and output as mentioned above.  So,
* we can represent the 64 theoretical possibilities in the 16 supported instructions.
* 
*///==================================================================================================================



/*****************************************************************************************************************//**
* The following section is the common code used to program the EEPROM.  This section will be repeated with each 
* separate piece of firmware (at least unless/until I can figure out how to tell the Arduino IDE to import something
* from another folder).
* 
* In the meantime, I expect to have to do multiple-maintenance on anything in this section.
*///==================================================================================================================



//
// -- Define some constants that will be used to interact with the Arduino
//    --------------------------------------------------------------------
#define PIN_DATA    2
#define PIN_CLOCK   3
#define PIN_LATCH   4

#define DATA0       5
#define DATA7       12
#define WRITE_EN    13


//
// -- Set an address to be read from/written to
//    -----------------------------------------
void setAddress(int address, bool outputEnable) {
  address &= 0x7ff;       // safety first -- make sure the address is only 11 bits wide
  digitalWrite(WRITE_EN, HIGH);
  delay(1);

  shiftOut(PIN_DATA, PIN_CLOCK, MSBFIRST, (address >> 8) | (outputEnable ? 0x00 : 0x80));
  shiftOut(PIN_DATA, PIN_CLOCK, MSBFIRST, address & 0xff);

  delay(1);

  digitalWrite(PIN_LATCH, LOW);
  digitalWrite(PIN_LATCH, HIGH);
  digitalWrite(PIN_LATCH, LOW);

  delay(1);
}


//
// -- Write a single byte of data to an address in the EEPROM
//    -------------------------------------------------------
void writeEeprom(int address, byte data) {
  setAddress(address, false);

  for (int pin = DATA0; pin <= DATA7; pin ++) {
    pinMode(pin, OUTPUT);
  }

  for (int pin = DATA0; pin <= DATA7; pin ++) {
    digitalWrite(pin, data & 1);
    data = data >> 1;
  }

  digitalWrite(WRITE_EN, LOW);
  delayMicroseconds(1);
  digitalWrite(WRITE_EN, HIGH);
  delay(30);
}



//
// -- Read a single byte from an address on the EEPROM
//    ------------------------------------------------
byte readEeprom(int address) {
  setAddress(address, true);
  
  for (int pin = DATA7; pin >= DATA0; pin --) {
    pinMode(pin, INPUT);
  }

  byte data = 0;

  for (int pin = DATA7; pin >= DATA0; pin --) {
    data = (data << 1) | digitalRead(pin);
  }

  return data;
}


//
// -- Dump the contents of the entire EEPROM to the Serial Port
//    ---------------------------------------------------------
void dumpEeprom(void) {
  char buf [80];
  
  Serial.println();
  Serial.println("Dumping the contents of the Eeprom\n");
  Serial.println();
  Serial.println("       0x00 0x01 0x02 0x03 0x04 0x05 0x06 0x07   0x08 0x09 0x0a 0x0b 0x0c 0x0d 0x0e 0x0f");
  Serial.println("       ---- ---- ---- ---- ---- ---- ---- ----   ---- ---- ---- ---- ---- ---- ---- ----");

  for (int base = 0; base < 2048; base += 16) {
    sprintf(buf, "0x%03x: ", base);
    Serial.print(buf);

    for (int offset = 0; offset < 16; offset ++) {
      int addr = base + offset;
      sprintf(buf, "0x%02x ", readEeprom(addr));
      Serial.print(buf);

      if (offset == 7) Serial.print("  ");
    }

    Serial.println();
  }
}


//
// -- Erase the EEPROM back to factory (burns one of the write cycles)
//    ----------------------------------------------------------------
void eraseEeprom(void) {
  Serial.print("Erasing EEPROM");
  
  for (int i = 0; i < 2048; i ++) {
    writeEeprom(i, 0xff);
    
    if (i % 32 == 0) Serial.print(".");
  }

  Serial.println();
}



//
// -- Perform the EEPROM programmer initialization
//    --------------------------------------------
void performInitialization() {
  digitalWrite(PIN_LATCH, LOW);
  digitalWrite(PIN_CLOCK, LOW);
  digitalWrite(PIN_DATA, LOW);
  digitalWrite(WRITE_EN, HIGH);

  pinMode(PIN_DATA, OUTPUT);
  pinMode(PIN_CLOCK, OUTPUT);
  pinMode(PIN_LATCH, OUTPUT);
  pinMode(WRITE_EN, OUTPUT);
}



/*****************************************************************************************************************//**
* The following section is directly the task to complete.  
* 
* In this case we are programming the ALU firmware.  We will have 5 input lines (address lines) for the 4 control
* lines and 1 carry bit.  Output will be 4 control lines, 1 mode line, and 1 carry inversion control signal.
* 
* Now for orgainization:
* - The lowest 4 bits of the address will handle the 4 control lines coming from the Control Module.
* - The next highest bit (1<<4) will handle the carry-bit input, meaning that most of the lower 16 bytes and next 
*   16 bytes will remain the same.
* - The remaining 3 bits will remain unused and will be assumed to be 0, leaving that section of the EEPROM 
*   unprogrammed.
*///==================================================================================================================
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

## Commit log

2022-01-29 Program Counter Wired-Up
    [clock-module.kicad_pcb, clock-module.kicad_sch]
2022-01-29 Program Counter Module Complete
    [clock-module.kicad_pcb, clock-module.kicad_sch, program-counter-module.kicad_pcb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]
2022-01-30 Add a reset button to the Power-Up Module
    [power-reset-module.kicad_pcb, power-reset-module.kicad_sch, program-counter-module.kicad_sch]
2022-02-01 Complete the Temporary Register Module
    [temporary-register-module.kicad_pcb, temporary-register-module.kicad_sch]
2022-02-12 Start the Mem Addr Module and complete the A Register
    [Mircocode.xlsx, memory-address-register.kicad_pcb, memory-address-register.kicad_sch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]
2022-02-20 Complete ALU (no flags work)
    [Labels.xlsx]
2022-02-21 Complete ALU wire-up
2022-02-25 Complete the ALU
    [30-Upper-Temporary-Register-1.kicad_pcb, 30-Upper-Temporary-Register-1.kicad_sch, 31-Lower-Temporary-Register-1.kicad_pcb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]
2022-03-13 Start emulator and complete clock module
    [10-Clock.kicad_pcb, 10-Clock.kicad_sch, 11-Upper-Memory-Address-Register.kicad_pcb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]
2022-03-27 Create a functional assembler
    [13-Memory-Contents.kicad_pcb, 13-Memory-Contents.kicad_sch, 14-Memory-RAM.kicad_pcb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]
